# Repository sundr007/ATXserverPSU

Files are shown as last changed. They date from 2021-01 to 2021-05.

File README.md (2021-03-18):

# ATXserverPSU
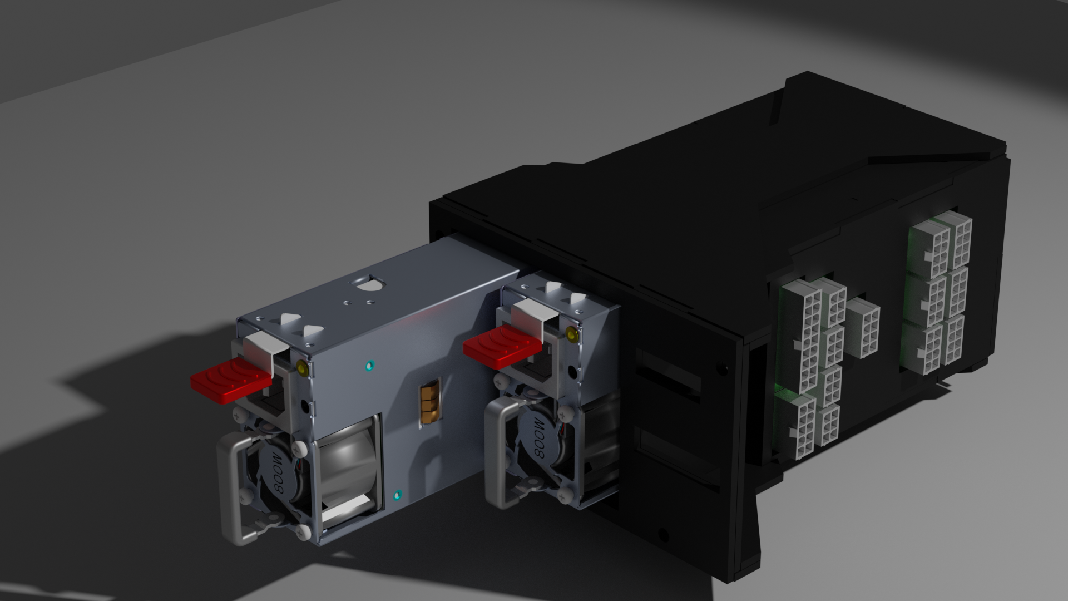
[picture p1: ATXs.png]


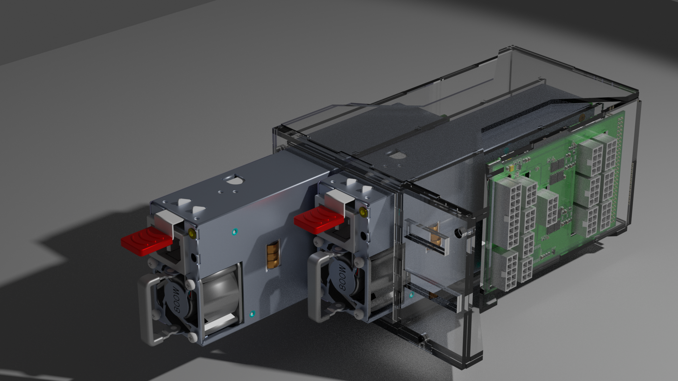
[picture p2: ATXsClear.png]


ATX computer power supply utilizing redundant server power supplies for mining applications.
The Server power supplies will converter AC to 12Vdc with high efficiency.
The ATXs box will then take that 12V, create 5V and 3.3V, supply the needed logic and then provide a modular ATX connector set to connect to the mother board, graphics cards, etc.

The biggest benefit of this system is that the server power supplies will provide very high output power at high efficiency.

The circuit boards are done in KiCAD.
The mechanicals are done in OpenSCAD.

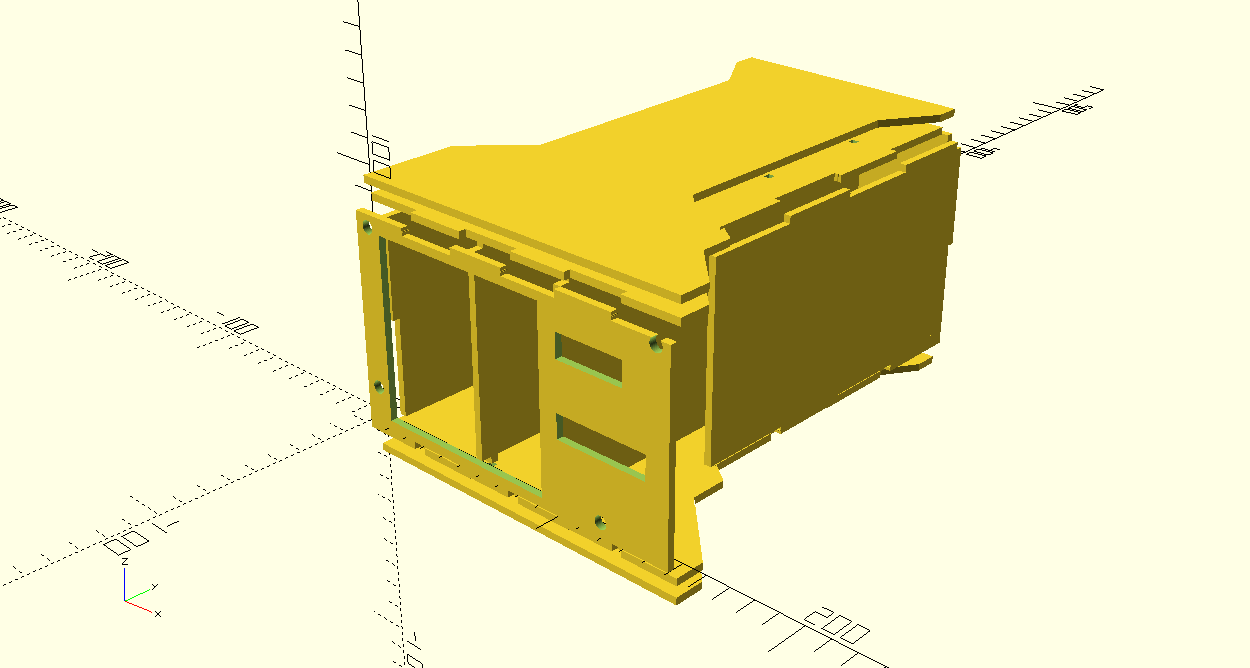
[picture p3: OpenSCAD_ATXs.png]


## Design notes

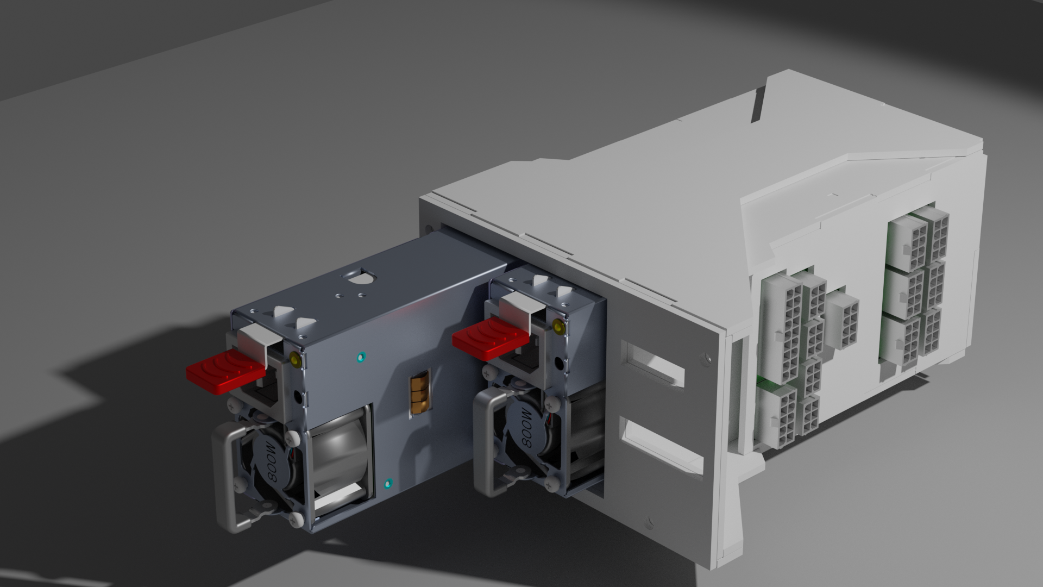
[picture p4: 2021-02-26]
ATXsWhite.png

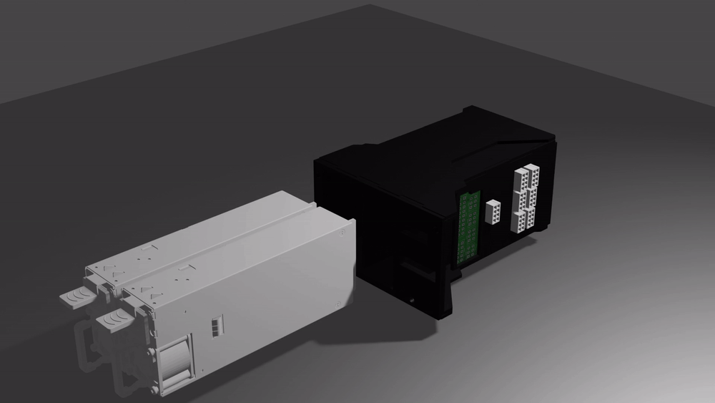
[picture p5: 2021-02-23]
Blender/output.gif

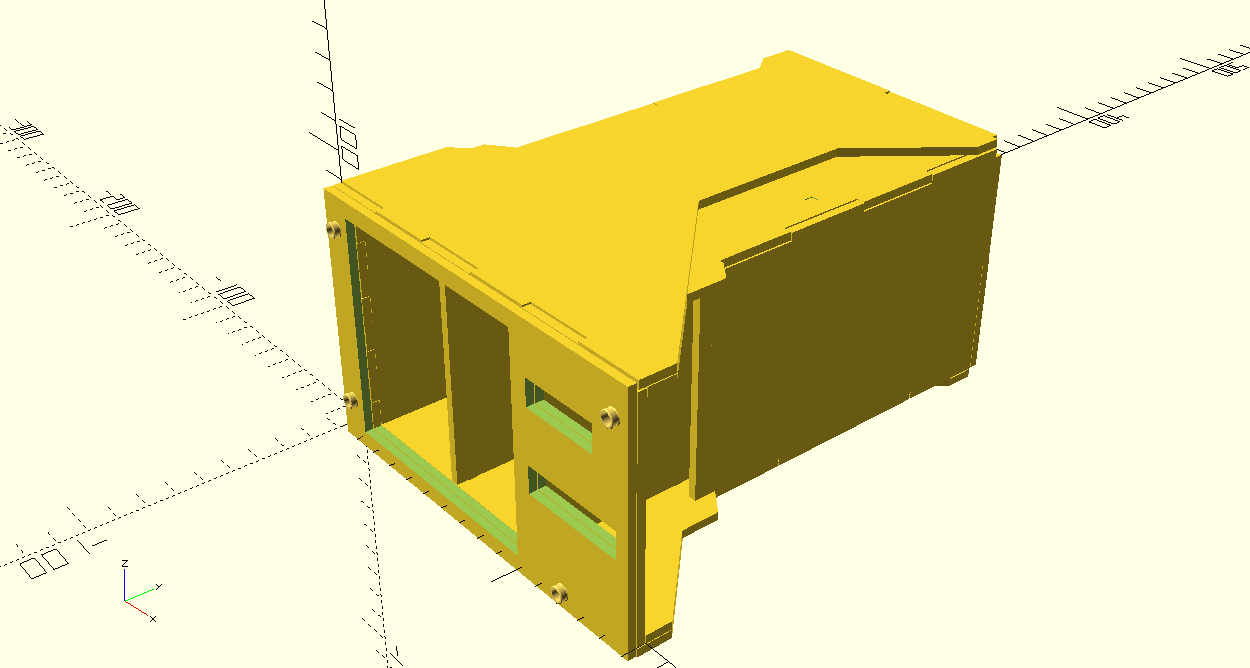
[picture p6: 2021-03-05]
ME-OpenSCAD/ATXs.png

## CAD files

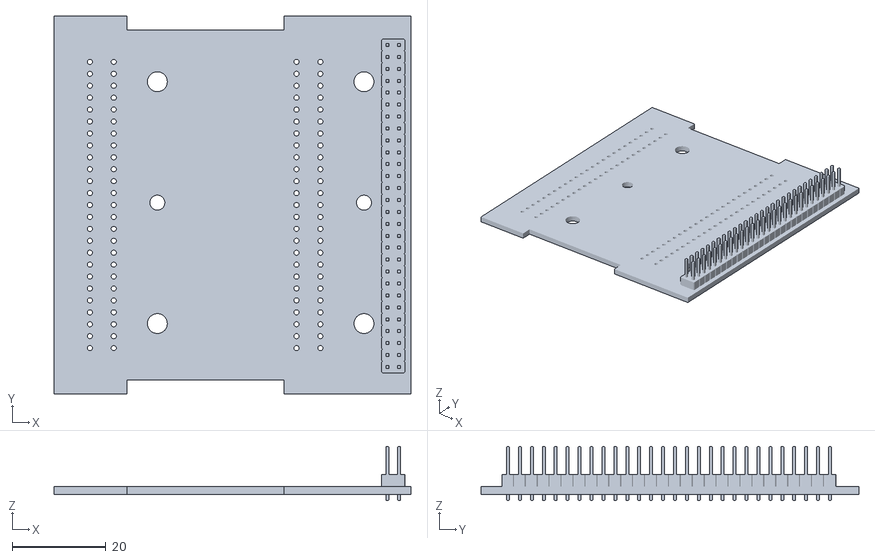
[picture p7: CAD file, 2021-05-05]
ME-OpenSCAD/PCBPSU.stl
76.0 x 80.5 x 11.5

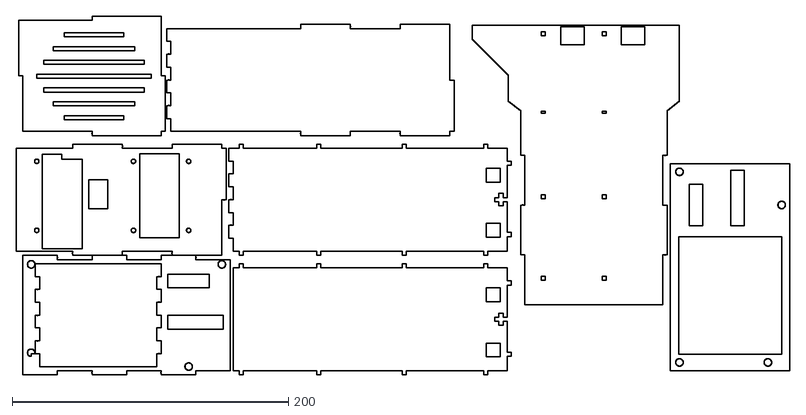
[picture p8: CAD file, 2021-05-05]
ME-OpenSCAD/ATXs1.dxf
560.3 x 259.7

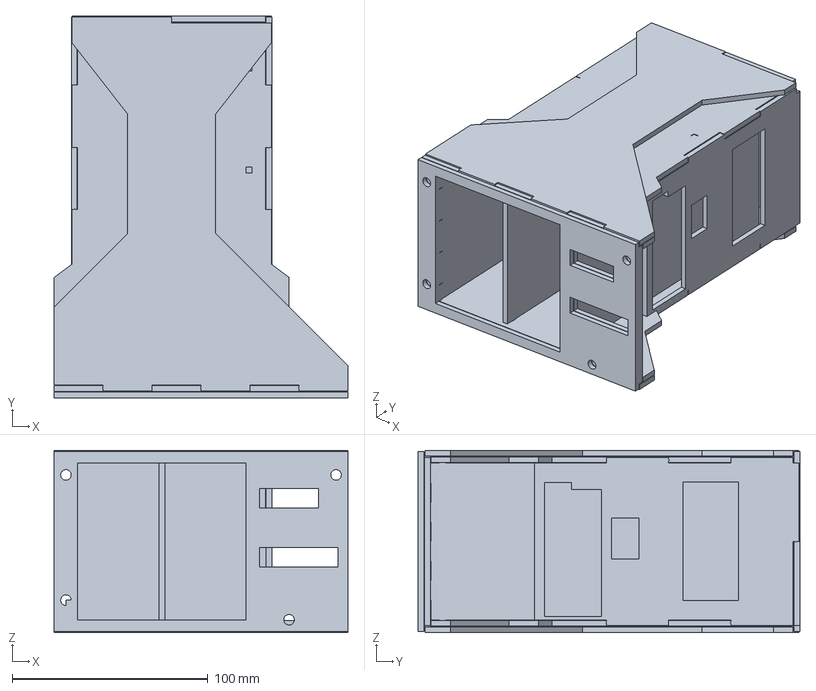
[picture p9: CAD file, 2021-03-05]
ME-OpenSCAD/ATXs.3mf
150.0 x 195.2 x 93.2 mm

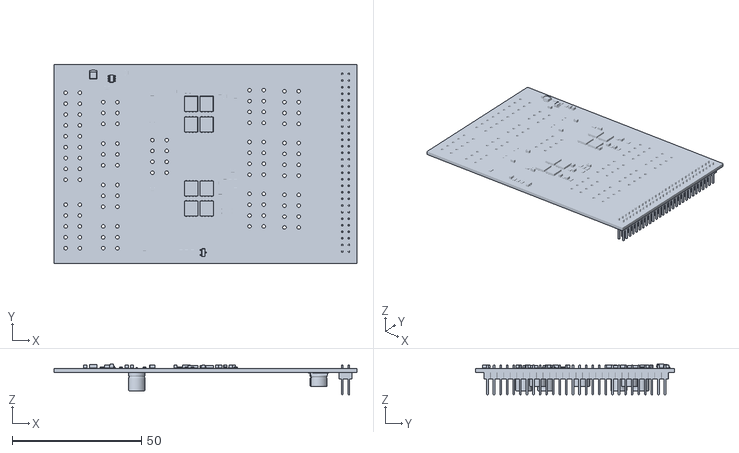
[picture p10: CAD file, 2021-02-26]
ME-OpenSCAD/PCBATX.stl
117.0 x 77.0 x 11.8

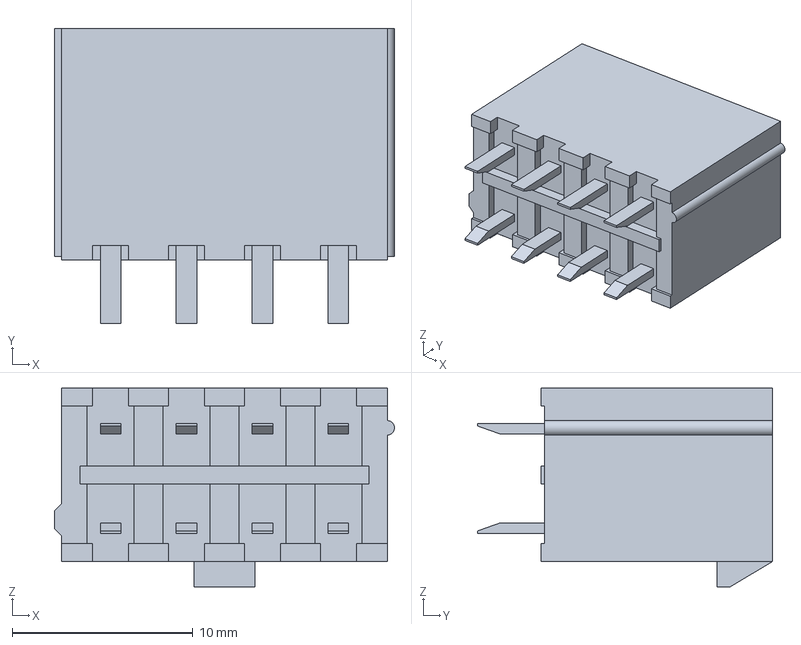
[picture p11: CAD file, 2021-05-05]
Blender/2x8.stp
18.8 x 16.3 x 11.0 mm

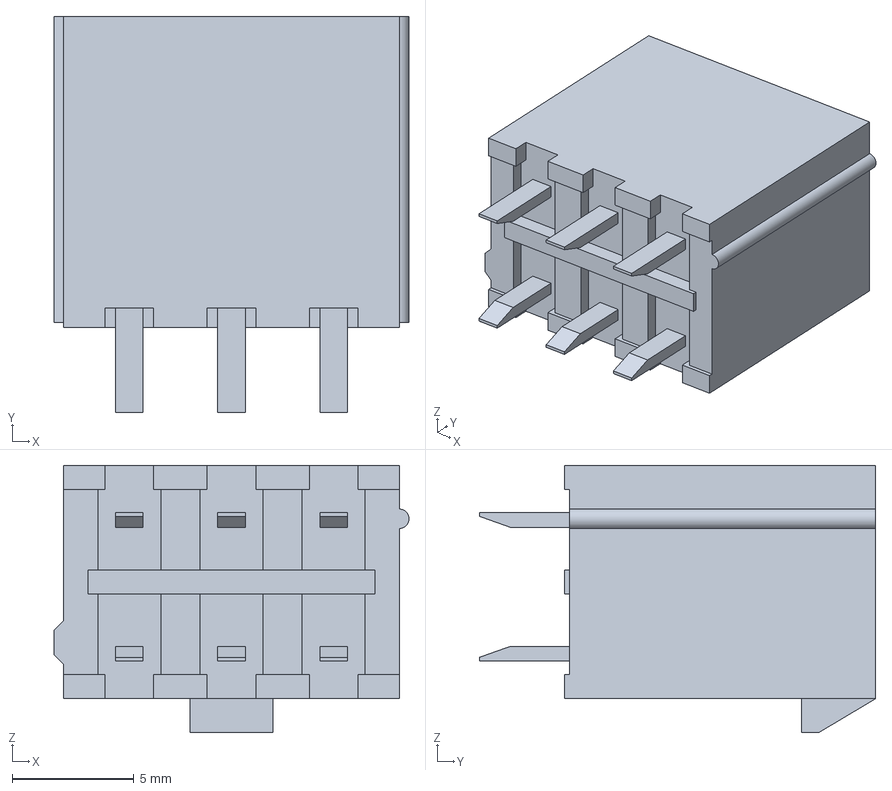
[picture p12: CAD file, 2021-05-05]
Blender/039288060.stp
14.6 x 16.3 x 11.0 mm

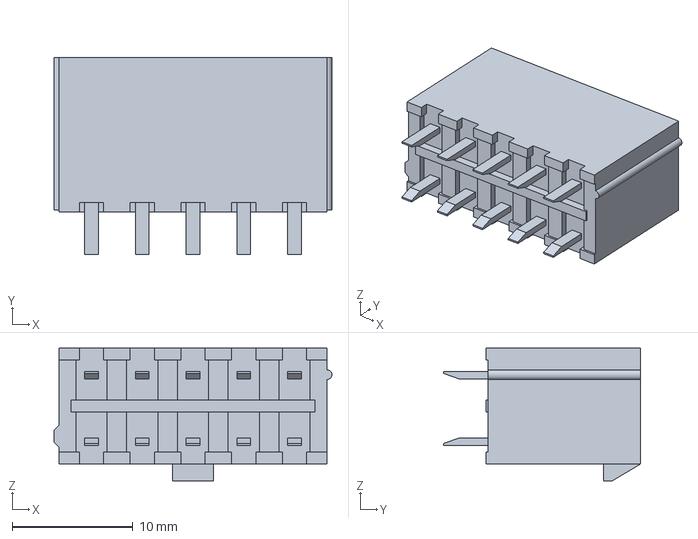
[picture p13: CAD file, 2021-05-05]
Blender/039288100.stp
23.0 x 16.3 x 11.0 mm

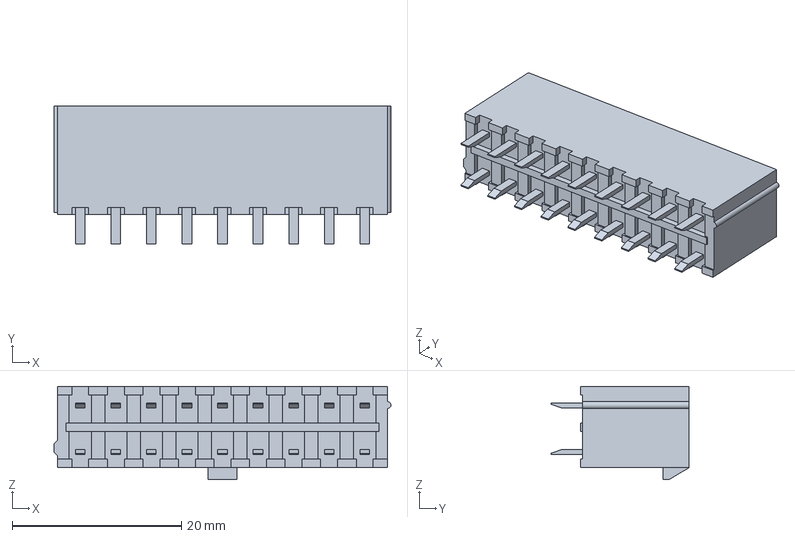
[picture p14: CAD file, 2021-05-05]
Blender/039288180.stp
39.8 x 16.3 x 11.0 mm

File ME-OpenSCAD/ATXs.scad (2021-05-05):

include </home/evan/github/lasercut/lasercut.scad>; 
include <Hex.scad>; 


module ATX_PCB(){
import("PCBATX.stl");
}
module PSU_PCB(){
 import("PCBPSU.stl");
}
module PSU(){
import("PSU.stl");
}

$fn=60;
// ##### RENDERING OPTIONS #####

render_3d   = true;
render_2d   = false;
render_2d2  = false;
render_pcbATX   = false;


// Part Seperation
Sep=10-10*$t;
Sep=0.1;

thickness = 3;

Tape_thickness= 2;
PCB_Thickness = 1.575;
// ATX Front Plate
W = 150;


Hpsu=41;
Lpsu=186;
Wpsu=74.5;
ATXgap=12+3;
PSU_to_psuPCB=18.5;
Backgap=PSU_to_psuPCB- thickness*2+PCB_Thickness+Tape_thickness;

H = Wpsu+thickness*1;

// Top Plate
Wfront = 150;
Wback  = (Hpsu+thickness)*2+ATXgap+thickness;
L      = Lpsu+Backgap;
L1     = 55;
Xindent= 9;
angle =45;
yindent=Xindent*tan(angle);
Yfrontpanelthick=10;

//
Ybacksq = L-(L1+yindent)+6;
Xseperator1 = Xindent+Hpsu+thickness;
Xseperator2 = Xindent+(Hpsu+thickness)*2;
Lseperator  = Lpsu - thickness*2+PSU_to_psuPCB;

// ATX PCB

Watx = Ybacksq -10;
Hatx = H-6; 
PCB_Thick=10;



module pcbATX(){
    //cube([Watx,Hatx,PCB_Thickness]);
ATX_PCB();    
}
module pcbATX3d(){
    translate([Xindent+Wback-thickness+3*Sep-thickness-1.5+0,Lseperator+PCB_Thickness-112.25,thickness])
    rotate([90,0,0])
    rotate([0,90,0])
    color("green",0.5)
    pcbATX();
   

}

module pcbPSU3d(){
    translate([Xseperator2+thickness-75.5+8,Lseperator+PCB_Thickness,thickness])
    rotate([90,0,0])
    color("green",0.5)
    PSU_PCB();
}

module PSU3d(){
       translate([Xindent+Hpsu+2,Lpsu/2-thickness*2,Wpsu/2+thickness])
    rotate([0,0,90])
    color("white",0.5)
    PSU(); 

       translate([Xindent+Hpsu*2+thickness+2,Lpsu/2-thickness*2,Wpsu/2+thickness])
    rotate([0,0,90])
    color("white",0.5)
    PSU(); 
    
    
}

module pcbATX2d(){
    kerf=0.1;
    projection(){
    pcbATX();
        }
}


// ================================================
// Define 3D View
// ================================================

module 3d() {
    FrontMetal3d();
    Front3d();
    Right3d();
    Sep13d();
    Sep23d();
    Top3d();
    Bottom3d();
    Back3d();
    Left3d();
    pcbATX3d();
    pcbPSU3d();
   // PSU3d();
}

// ================================================
// Define 2D View
// ================================================

module 2d() {
    kerf=0.1;
    z=200;
    H=H+thickness*3+.1;
    Wfront=Wfront+thickness*5+.1;
    projection()
    {
            FrontPlateAcrylic();
        translate([0,H, 0]) 
            right();
        translate([0, H*2, 0]) 
            back();
        translate([Wfront-13, 0, 0])  
            Seperator();
        translate([Wfront-13, H, 0])  
            Seperator(1);
        translate([Wfront, H*2, 0])  
            left();
        translate([Wfront*3-20, 250, 0])  
            rotate([0,0,180])
            topPlate();
        translate([Wfront*3+60, 0, 0])  
            rotate([0,0,90])
        FrontPlateMetal();

    }   
}

module 2d2() {
    kerf=0.1;
    z=200;
    H=H+thickness*3+.1;
    Wfront=Wfront+thickness*5+.1;
    projection()
    {



            topPlate();
        translate([Wfront*1, 0, 0])
            topTrim();
        translate([Wfront*2, 0, 0])
            topTrim();
    }}



// ================================================
// Part Positioning
// ================================================
module FrontMetal3d(){
translate([0,-thickness*1-6*Sep,-thickness])
    rotate([90,0,0])
        FrontPlateMetal();
}
module Front3d(){
translate([0,-3*Sep,0])
    rotate([90,0,0])
        FrontPlateAcrylic();
}
module Right3d(){
translate([Xindent+Wback-thickness+3*Sep,L-Ybacksq,thickness])
    rotate([90,0,90])
        right();
}
module Sep13d(){
translate([Xseperator1,0,thickness])
    rotate([90,0,90])
        Seperator();
}
module Sep23d(){
translate([Xseperator2,0,thickness])
    rotate([90,0,90])
        Seperator(1);
}
module Top3d(){
translate([0,0,H+Sep*3]){
    top();
}
}
module Bottom3d(){
translate([0,0,-Sep*3]){
    bottom();
}
}
module Back3d(){
rotate([90,0,0])
    translate([Xindent+thickness,0,-L-thickness-Sep*6])
        back();
    }
module Left3d(){
translate([Xindent-Sep*3,L-Ybacksq,thickness])
    rotate([90,0,90])
    left();
}


// ================================================
// Part Definitions
// ================================================

module topPlate()
{
    Wback = Wback - 2*thickness;
    Xindent = Xindent + thickness;
    L = L - thickness;
    
    points = [[0,0], [0,L1], [Xindent,L1+Xindent], [Xindent,L+yindent-thickness*2], [Xindent+Wback,L+yindent-thickness*2], [Xindent+Wback,L1+Xindent], [2*Xindent+Wback,L1], [2*Xindent+Wback,Yfrontpanelthick+(Wfront-(2*Xindent+Wback))], [Wfront,Yfrontpanelthick], [Wfront,0]];
    
    difference(){
        union(){
    lasercutout(thickness=thickness, points = points,
    simple_tab_holes=[
                [MID,Xseperator1, 0+thickness*1.5],
                [MID,Xseperator1, (Lpsu)*1/3-thickness/2],
                [MID,Xseperator1, (Lpsu)*2/3-thickness/2],
                [MID,Xseperator1, Lpsu-thickness*1.5],
    
                [MID,Xseperator2, 0+thickness*1.5],
                [MID,Xseperator2, (Lpsu)*1/3-thickness/2],
                [MID,Xseperator2, (Lpsu)*2/3-thickness/2],
                [MID,Xseperator2, Lpsu-thickness*1.5],
            ],
                    cutouts = [
            [Xindent+Hpsu/2-7.5, 1, 17, 13],
            [Xindent+Hpsu+thickness+Hpsu/2-7.5, 1, 17, 13],
            [Wback+7.8,87.5,1.7,27],
            [Wback+7.8,155.6,1.7,22.5],
            [Wback-19,L-0.65,28,1.7],
            [32,L-0.65,17,1.7],
            ]
    

    );
    translate([Xindent,L1+yindent-thickness*2,0])
        lasercutoutSquare(thickness=thickness, x=Wback, y=Ybacksq,
            bumpy_finger_joints=[
               // [UP, 1, 1],
                [LEFT, 1, 2],
                [RIGHT, 2, 2]
            ],
            cutouts = [
            [Xindent, 4, 87,Lpsu-(L1-thickness*3)]
    ]
    );
}}}

module topTrim()
{
    Wgap=45;
    L=L;
    Y1 = Yfrontpanelthick+(Wfront-(2*Xindent+Wback));
    Xinner1 = Xindent+(Wback-Wgap)/2;
    Xinner2 = Xinner1+Wgap;
    
    points = [[0,0], [0,Y1], [Xinner1,Y1+Xinner1], [Xinner1,L-Xinner1-Xindent], [Xindent,L-Yfrontpanelthick], [Xindent,L], [Xindent+Wback,L], [Xindent+Wback,L-Yfrontpanelthick], [Xinner2,L-Xinner1-Xindent], [Xinner2,Y1+Xinner1], [Wfront,Yfrontpanelthick], [Wfront,0]];
    lasercutout(thickness=thickness, points = points);  
    
    translate([Xindent,L-thickness,0])
        lasercutoutSquare(thickness=thickness, x=Wback, y=thickness,
            bumpy_finger_joints=[
                [UP, 1, 1]
            ]
    );
    
    translate([0,0,0])
        lasercutoutSquare(thickness=thickness, x=Wfront,        y=thickness/2,
            bumpy_finger_joints=[
                [DOWN, 1, 3]
            ]
    );
}

module top(){
    topPlate();
    translate([0,0,3+Sep*3])
        topTrim();
}

module bottom(){
    topPlate();
    translate([0,0,-3-Sep*3])
        topTrim();
}

module back()
{
    H=H-thickness;
    difference(){
    width = (Wback-2*thickness);
        
    lasercutoutSquare(thickness=thickness, x=Wback-2*thickness, y=H+thickness*2,
    bumpy_finger_joints=[
            [UP, 0, 1],
            [DOWN, 1, 1],
            [LEFT, 0, 1],
            [RIGHT, 0, 1]
        ],
        slits = [
        [RIGHT,width*0.7,10,width*(1-(1-0.70)*2)],
        [RIGHT,width*0.78,20,width*(1-(1-0.78)*2)],
        [RIGHT,width*0.85,30,width*(1-(1-0.85)*2)],
        [RIGHT,width*0.9,40,width*(1-(1-0.9)*2)],
        [RIGHT,width*0.85,50,width*(1-(1-0.85)*2)],
        [RIGHT,width*0.78,60,width*(1-(1-0.78)*2)],
        [RIGHT,width*0.70,70,width*(1-(1-0.7)*2)]
        ]
    );  
        
    radius = 3;
    latticeWidth = 13;
    latticeLength = 11;
    spacing = 2.1;
    height = 4;
//    translate([3,6,-0.5])
//    difference(){
//        cube([(latticeLength-1)*(spacing+radius*2)
//        ,(latticeWidth)*(spacing+radius),4]);
//    honeycomb(radius,latticeWidth,latticeLength,spacing,height);
//    }
        

    }
}
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

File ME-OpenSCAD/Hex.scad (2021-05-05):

//radius = 12;
//latticeWidth = 4;
//latticeLength = 3;
//spacing = 10;
//height = 1;

module honeycomb(radius,latticeWidth,latticeLength,spacing,height){
difference() {  

        linear_extrude(height) {
        for(j = [0:latticeWidth-1]) {
            translate([(((sqrt(3)*radius)+spacing)/2)*(j%2),sqrt(pow((((((sqrt(3)))*radius)+spacing)),2)-(pow(((((sqrt(3)*radius)+spacing))/2),2)))*j,0]) {
                for(i = [0:latticeLength-1]) {
                    translate([((sqrt(3)*radius*i)+spacing*i),0,0]) {
                        rotate([0,0,30]) {
                            circle(((sqrt(3)*radius)+(spacing*2))/sqrt(3), $fn = 6);
                        }
                    }
                }
            }
        }
    }
        linear_extrude(height) {
        for(j = [0:latticeWidth-1]) {
            translate([((sqrt(3)*radius)+spacing)/2*(j%2),sqrt((pow(((sqrt(3)*radius)+spacing),2))-(pow((((sqrt(3)*radius)+spacing))/2,2)))*j,0]) {
                for(i = [0:latticeLength-1]) {
                    translate([(sqrt(3)*radius*i)+spacing*i,0,0]) {
                        rotate([0,0,30]) {
                            circle(radius, $fn = 6);
                        }
                    }
                }
            }
        }
    } 


}
}

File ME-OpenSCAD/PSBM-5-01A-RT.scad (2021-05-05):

$fn=60;

cube([13,13,2+0.8],true);
translate([0,0,7.9/2])
cylinder(7.9,4.37/2,4.37/2,true);

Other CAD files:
Blender/psu.obj
Blender/2x8.stl
ME-OpenSCAD/ATXs.amf
ME-OpenSCAD/ATXs.stl
ME-OpenSCAD/pcbATX.dxf

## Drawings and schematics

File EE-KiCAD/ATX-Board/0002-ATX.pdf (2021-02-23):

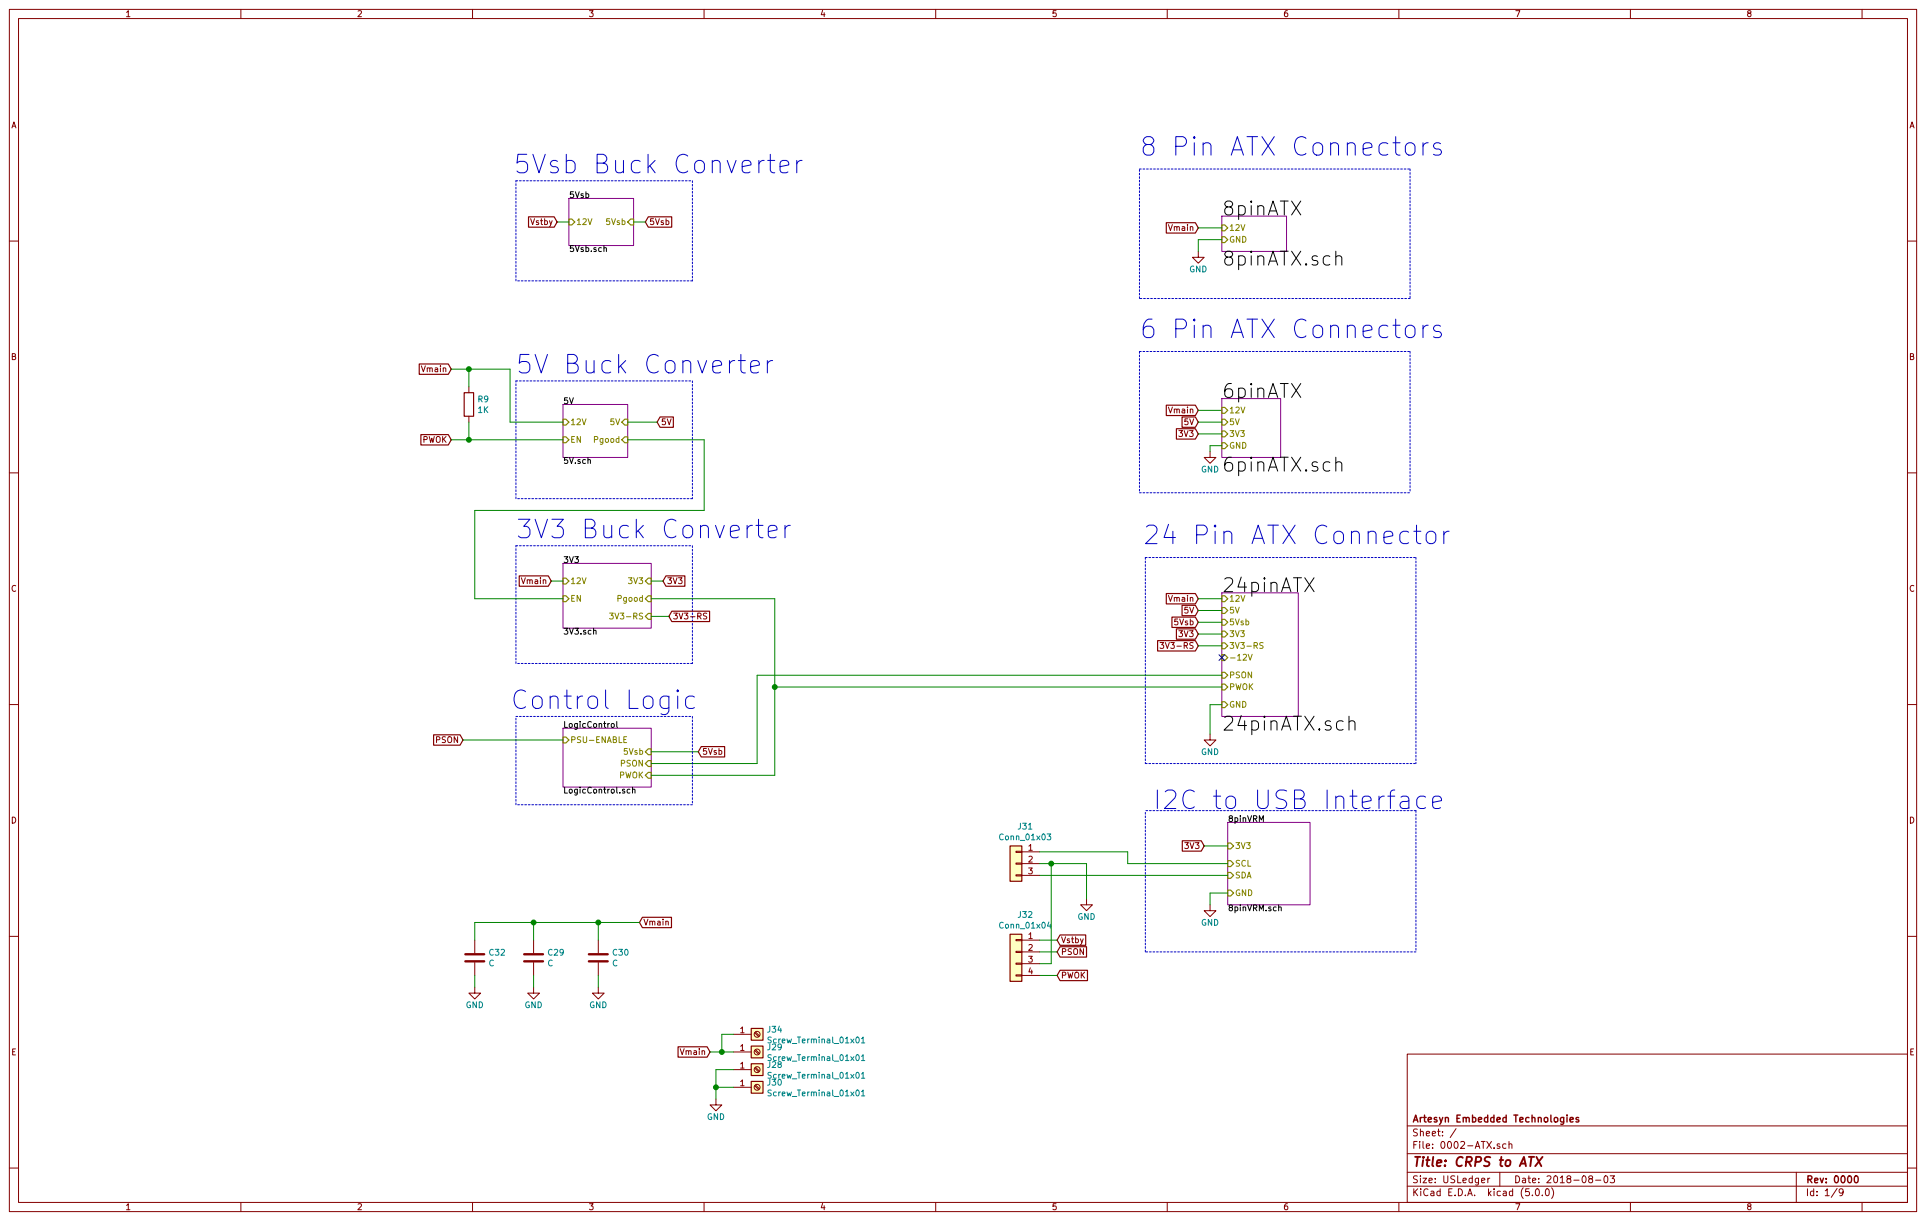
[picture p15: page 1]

Vmain 8 Pin ATX Connectors

Vmain 6 Pin ATX Connectors

Vmain 24 Pin ATX Connector

LogicControl
LogicControl.sch PSU-ENABLE

Id: 1/9 Title: CRPS to ATX

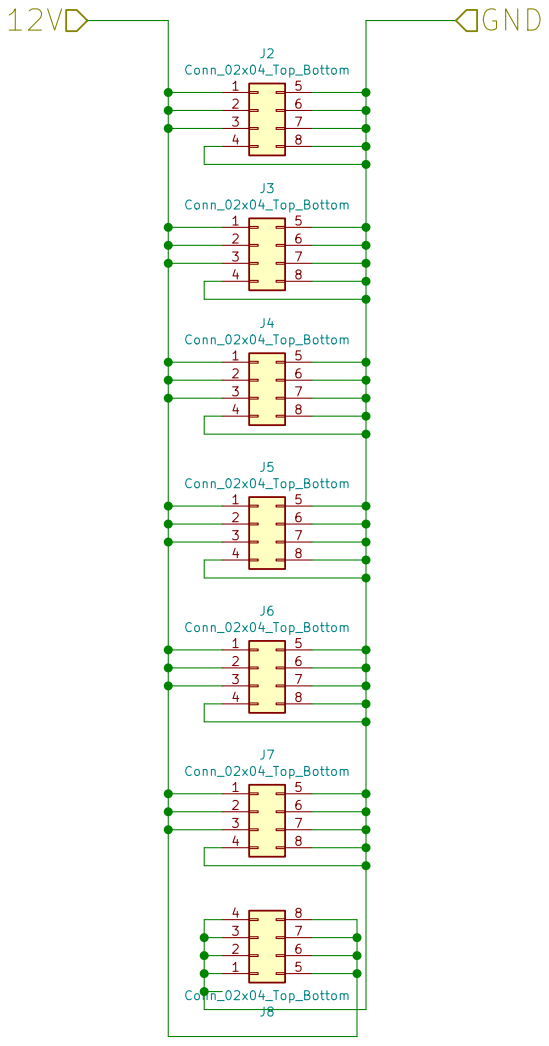
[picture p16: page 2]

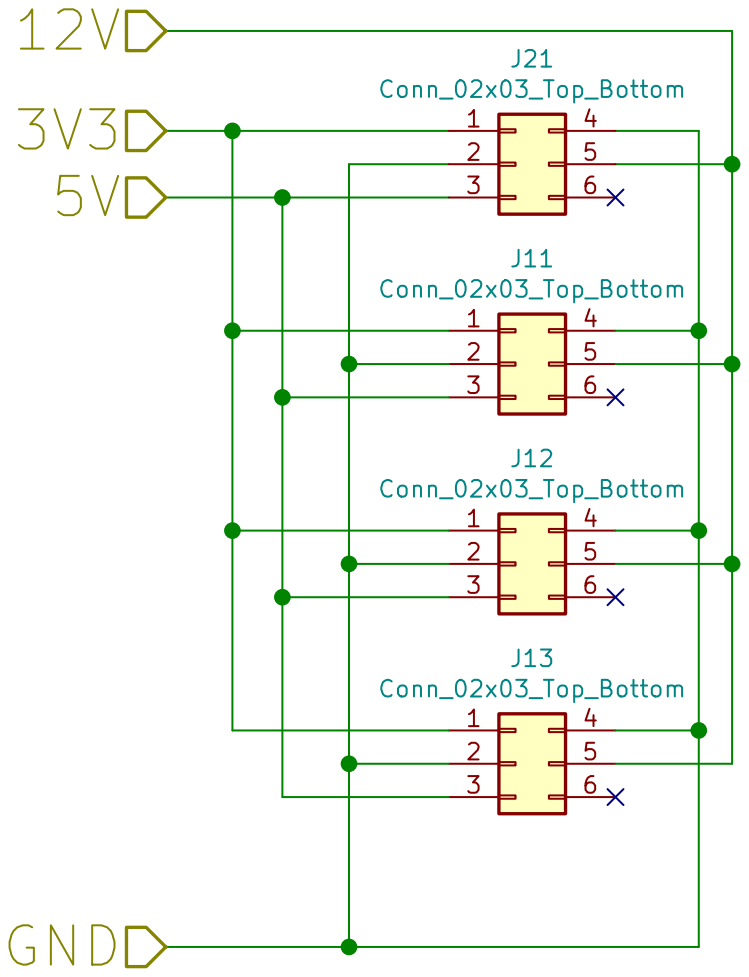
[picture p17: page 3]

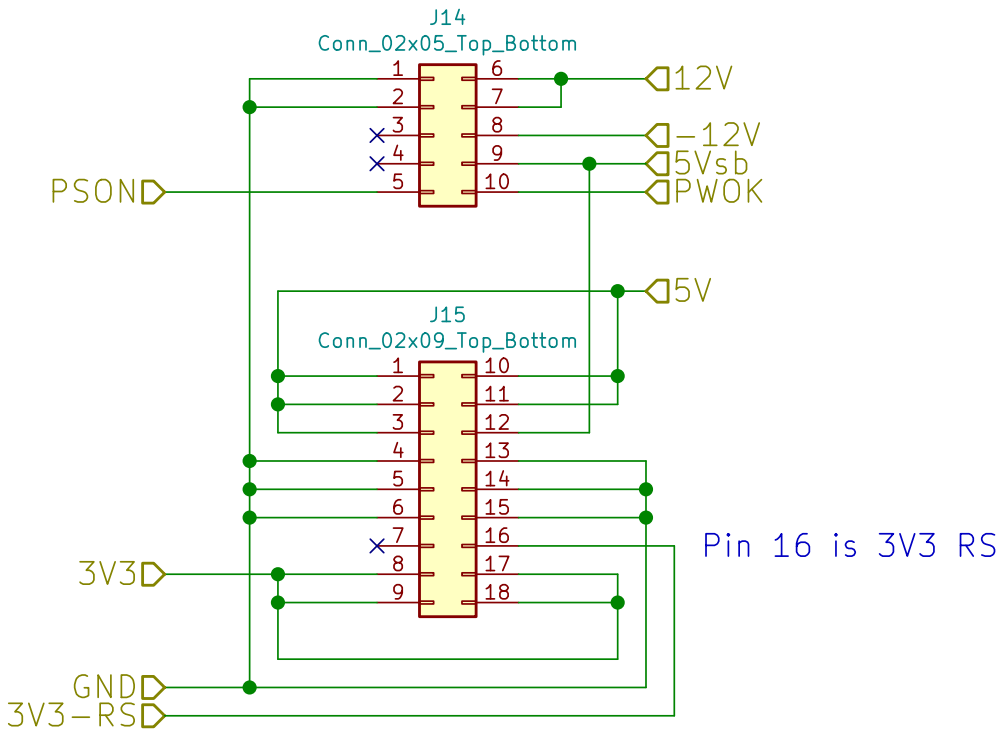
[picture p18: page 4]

J15 Conn_02x09_Top_Bottom

2 | 11
3 | 12

5 | 14
6 | 15
7 8 | 16

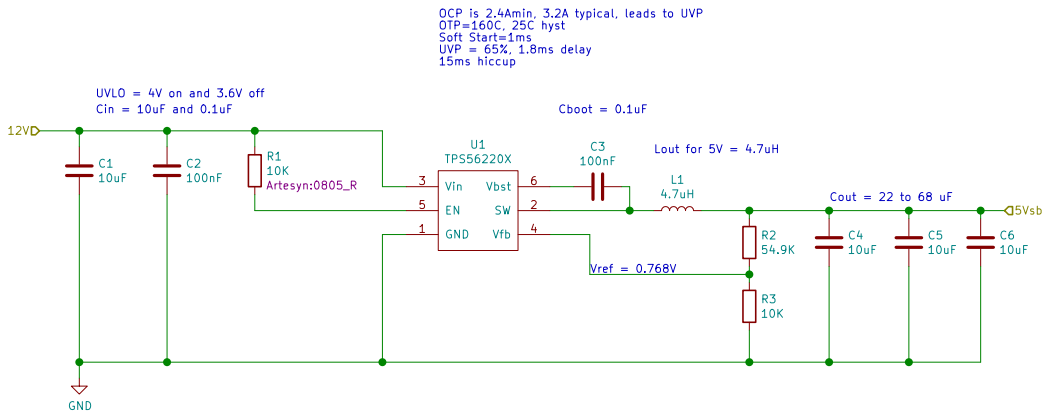
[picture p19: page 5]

Cout = 22 to 68 uF OCP is 2.4Amin, 3.2A typical, leads to UVP
OTP=160C, 25C hyst Soft Start=1ms UVP = 65%, 1.8ms delay

Id: 5/9 Title: File: 5Vsb.sch Sheet: /5Vsb/

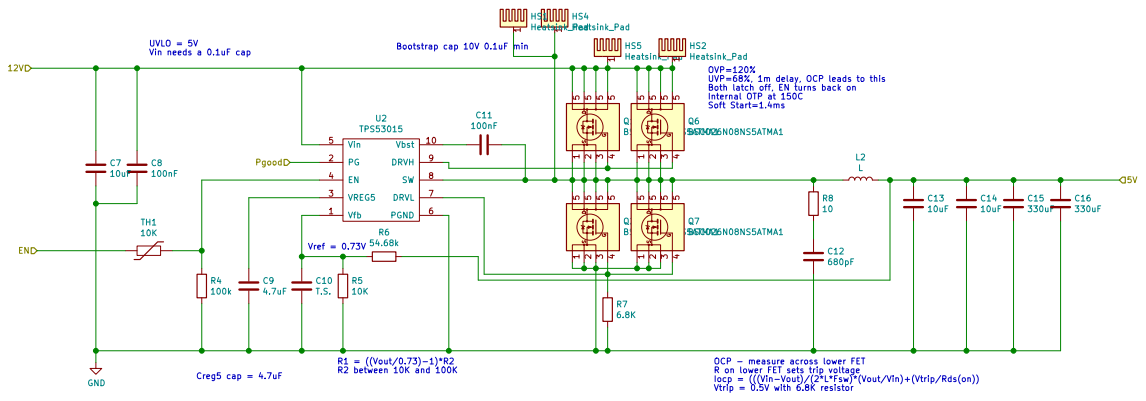
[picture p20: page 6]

UVP=68%, 1m delay, OCP leads to this Both latch off, EN turns back on
Internal OTP at 150C

Iocp = (((Vin-Vout)/(2*L*Fsw)*(Vout/Vin)+(Vtrip/Rds(on))
Vtrip = 0.5V with 6.8K resistor

Id: 6/9 Title: File: 5V.sch Sheet: /5V/

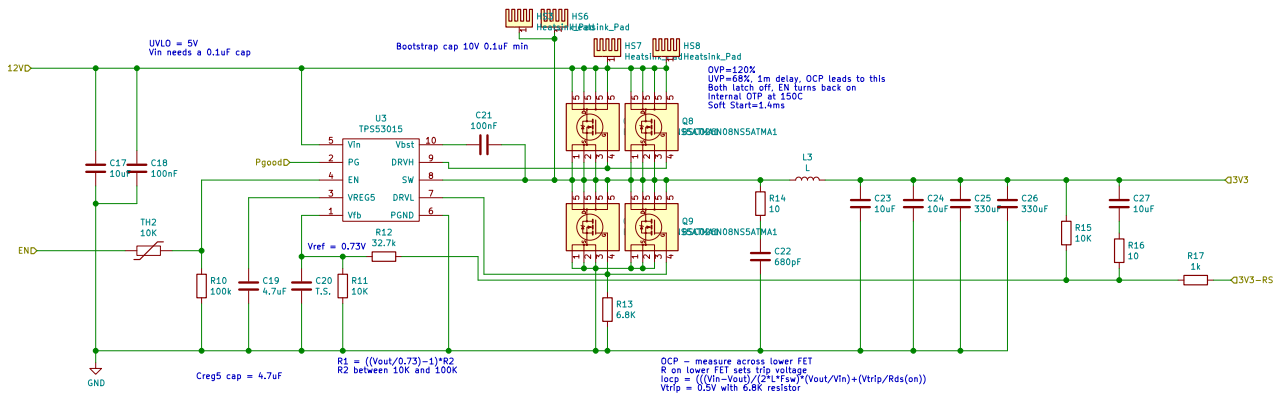
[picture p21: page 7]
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

Id: 7/9 Title: File: 3V3.sch Sheet: /3V3/

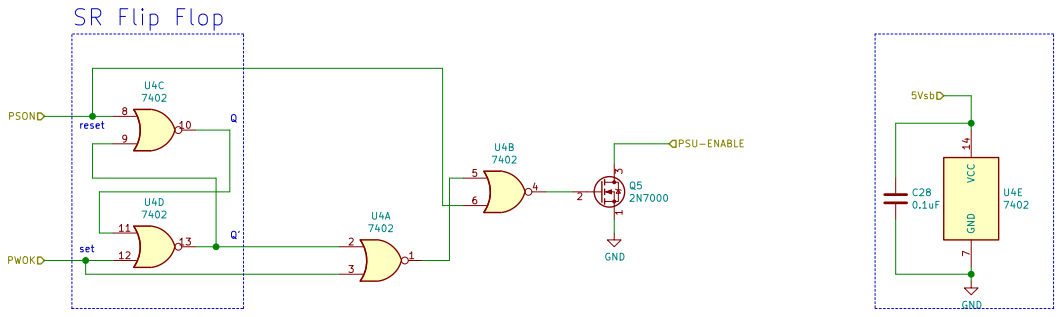
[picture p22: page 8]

7402 GND SR Flip Flop

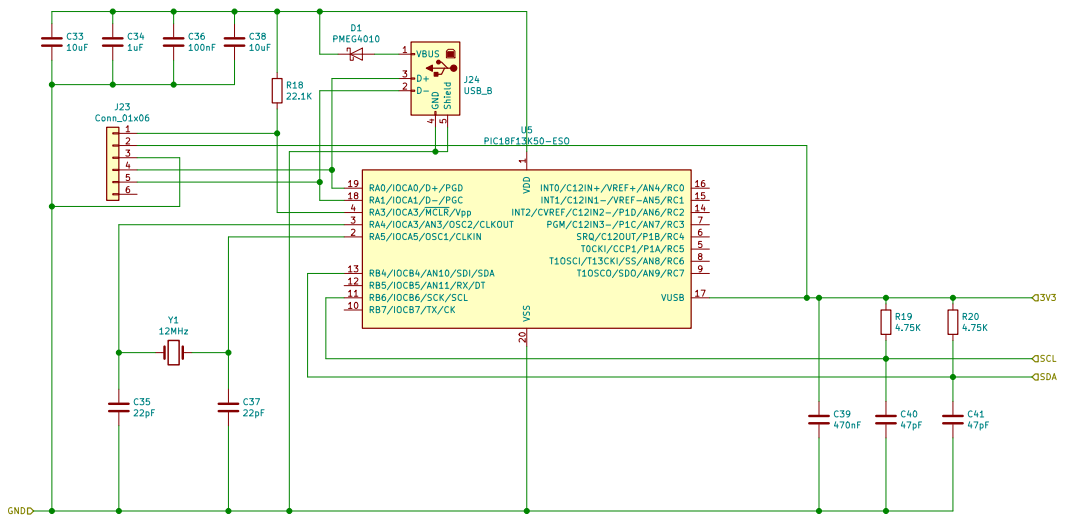
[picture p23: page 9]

1 RB7/IOCB7/TX/CK 10 RB6/IOCB6/SCK/SCL 11 RB5/IOCB5/AN11/RX/DT 12 RB4/IOCB4/AN10/SDI/SDA 13

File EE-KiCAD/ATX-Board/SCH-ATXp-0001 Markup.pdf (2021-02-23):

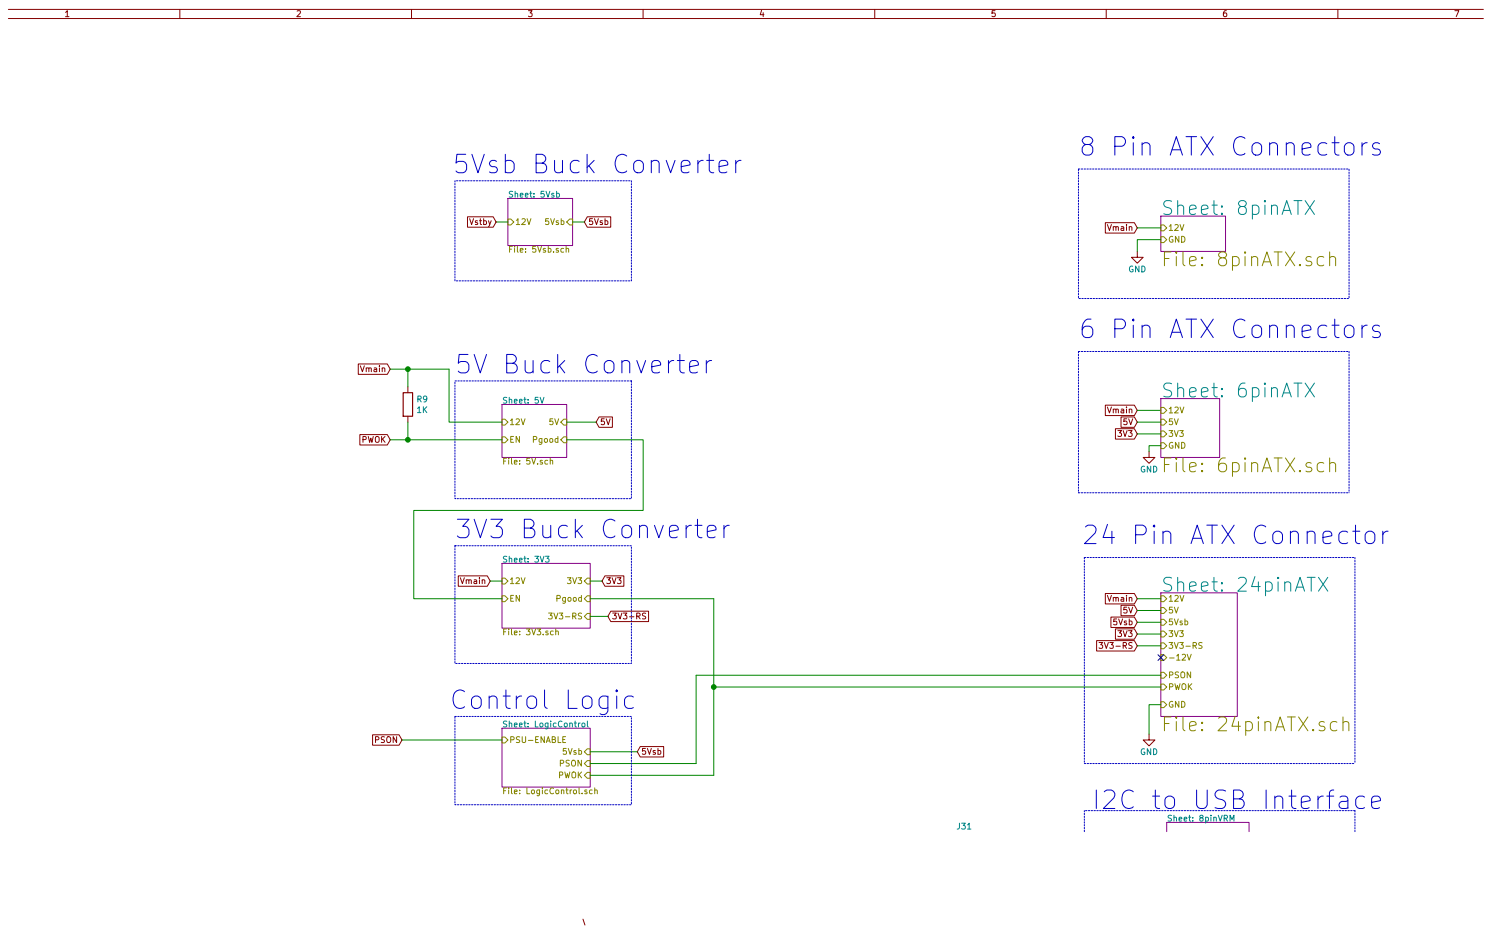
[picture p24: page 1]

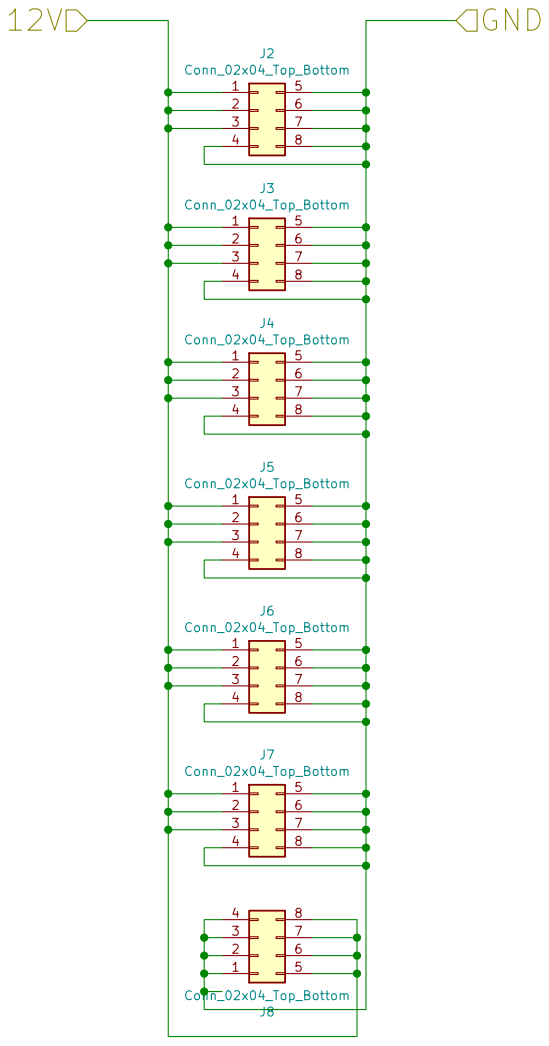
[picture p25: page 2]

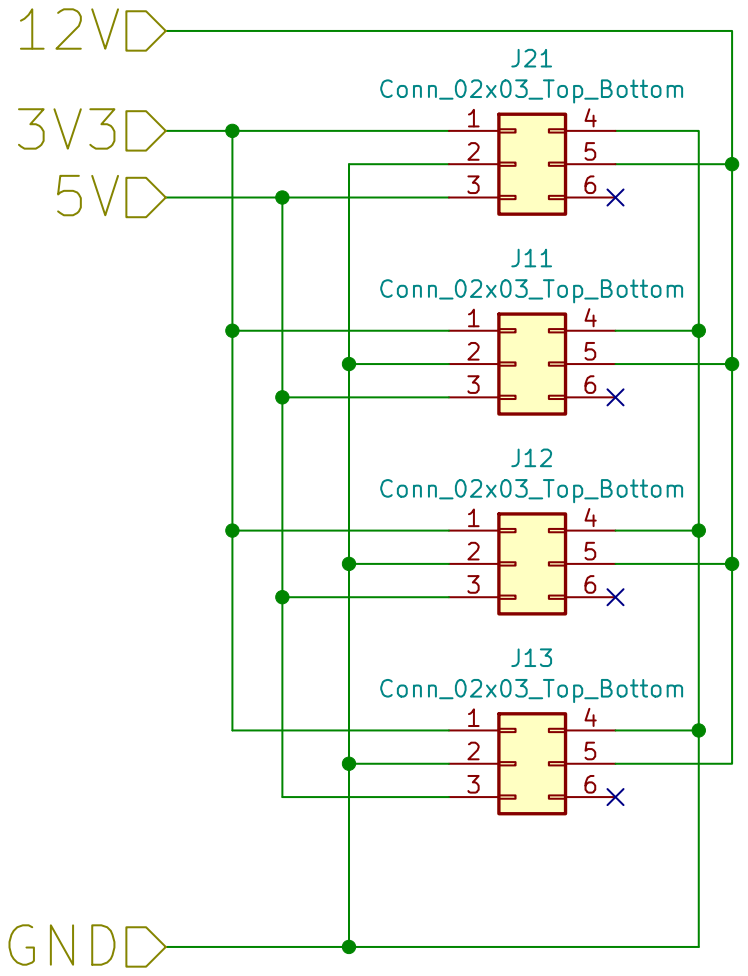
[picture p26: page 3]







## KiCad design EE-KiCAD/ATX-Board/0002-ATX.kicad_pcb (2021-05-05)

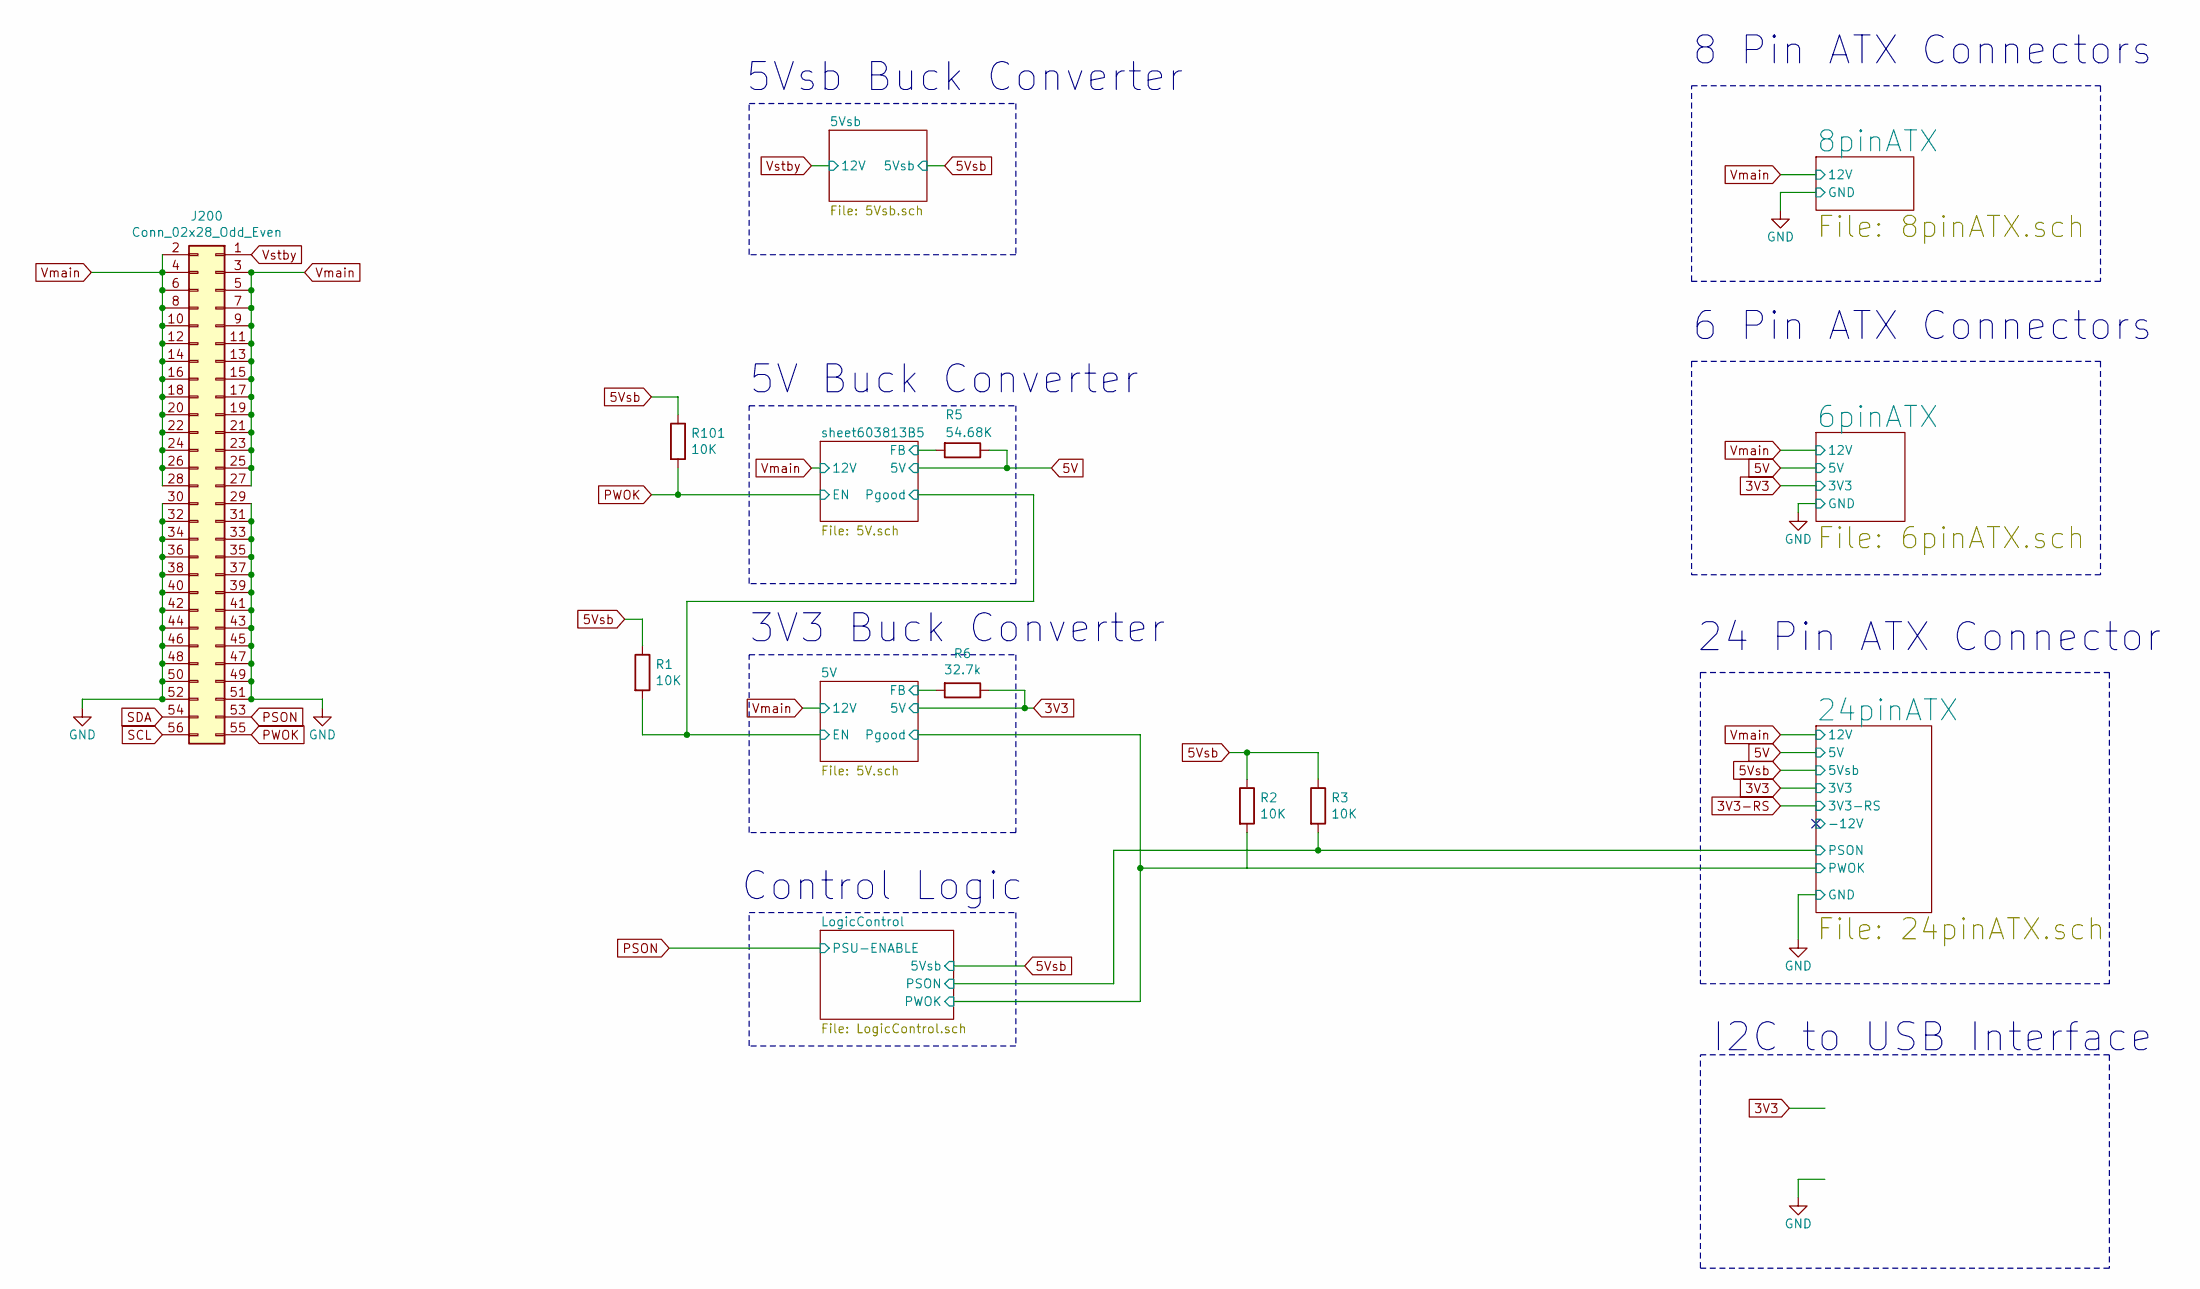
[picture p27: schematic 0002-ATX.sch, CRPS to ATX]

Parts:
J200: Conn_02x28_Odd_Even; PinSocket_2x28_P2.54mm_Horizontal
R1, R2, R3, R101: 10K; 0805_R
R5: 54.68K; 0805_R
R6: 32.7k; 0805_R

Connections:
3V3: R6.1; also elsewhere on the board
5V: R5.1; also elsewhere on the board
5Vsb: R1.1, R2.1, R3.1, R101.1; also elsewhere on the board
/5V/EN: R1.2; also elsewhere on the board
/5V/FB: R6.2; also elsewhere on the board
/24pinATX/PSON: R3.2; also elsewhere on the board
/sheet603813B5/FB: R5.2; also elsewhere on the board
GND: J200.29, J200.30, J200.31, J200.32, J200.33, J200.34, J200.35, J200.36, J200.37, J200.38, J200.39, J200.40, J200.41, J200.42, J200.43, J200.44, J200.45, J200.46, J200.47, J200.48, J200.49, J200.50, J200.51, J200.52; also elsewhere on the board
PSON: J200.53; also elsewhere on the board
PWOK: J200.55, R101.2; also elsewhere on the board
SCL: J200.56
SDA: J200.54
Vmain: J200.2, J200.3, J200.4, J200.5, J200.6, J200.7, J200.8, J200.9, J200.10, J200.11, J200.12, J200.13, J200.14, J200.15, J200.16, J200.17, J200.18, J200.19, J200.20, J200.21, J200.22, J200.23, J200.24, J200.25, J200.26, J200.27, J200.28; also elsewhere on the board
Vstby: J200.1; also elsewhere on the board

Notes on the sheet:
8 Pin ATX Connectors
6 Pin ATX Connectors
24 Pin ATX Connector
5Vsb Buck Converter
5V Buck Converter
3V3 Buck Converter
Control Logic
I2C to USB Interface

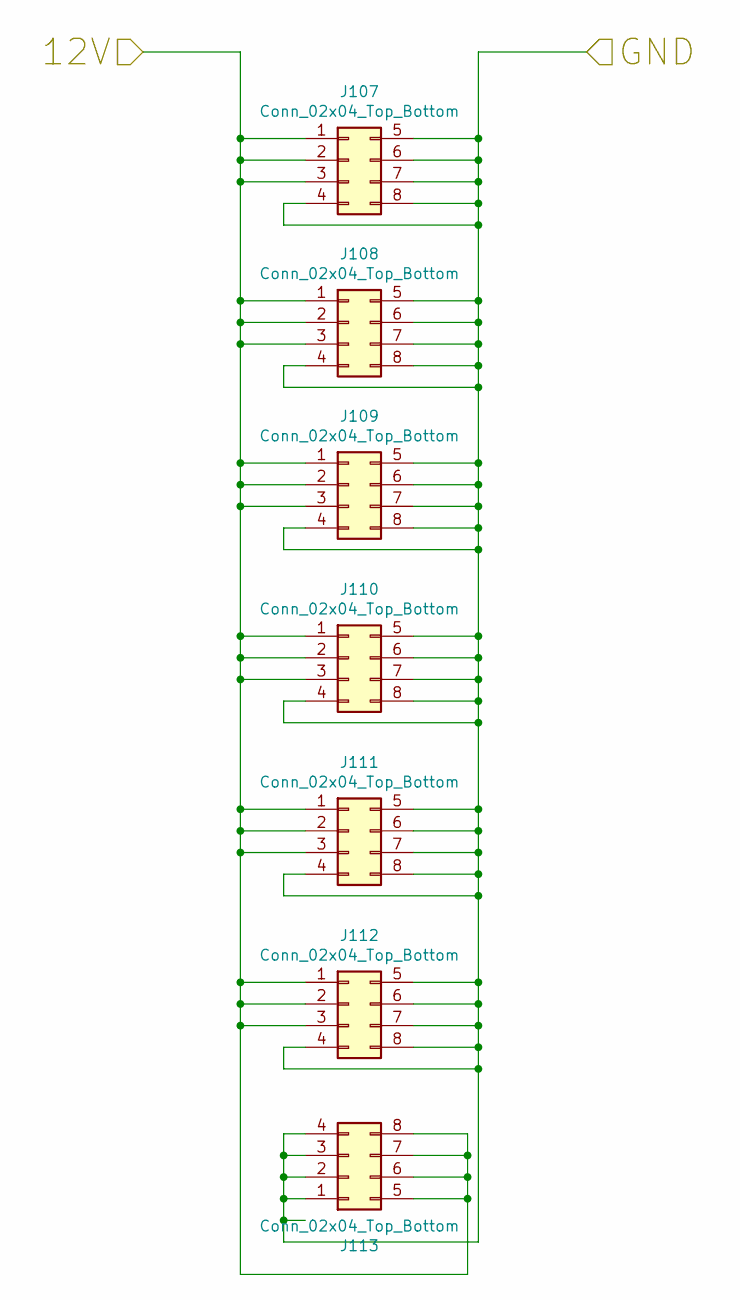
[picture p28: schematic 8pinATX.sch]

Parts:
J107, J108, J109, J110, J111, J112, J113: Conn_02x04_Top_Bottom; Molex_Mini-Fit_Jr_5566-08A_2x04_P4.20mm_Vertical

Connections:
GND: J107.4, J107.5, J107.6, J107.7, J107.8, J108.4, J108.5, J108.6, J108.7, J108.8, J109.4, J109.5, J109.6, J109.7, J109.8, J110.4, J110.5, J110.6, J110.7, J110.8, J111.4, J111.5, J111.6, J111.7, J111.8, J112.4, J112.5, J112.6, J112.7, J112.8, J113.1, J113.2, J113.3, J113.4; also elsewhere on the board
Vmain: J107.1, J107.2, J107.3, J108.1, J108.2, J108.3, J109.1, J109.2, J109.3, J110.1, J110.2, J110.3, J111.1, J111.2, J111.3, J112.1, J112.2, J112.3, J113.5, J113.6, J113.7, J113.8; also elsewhere on the board

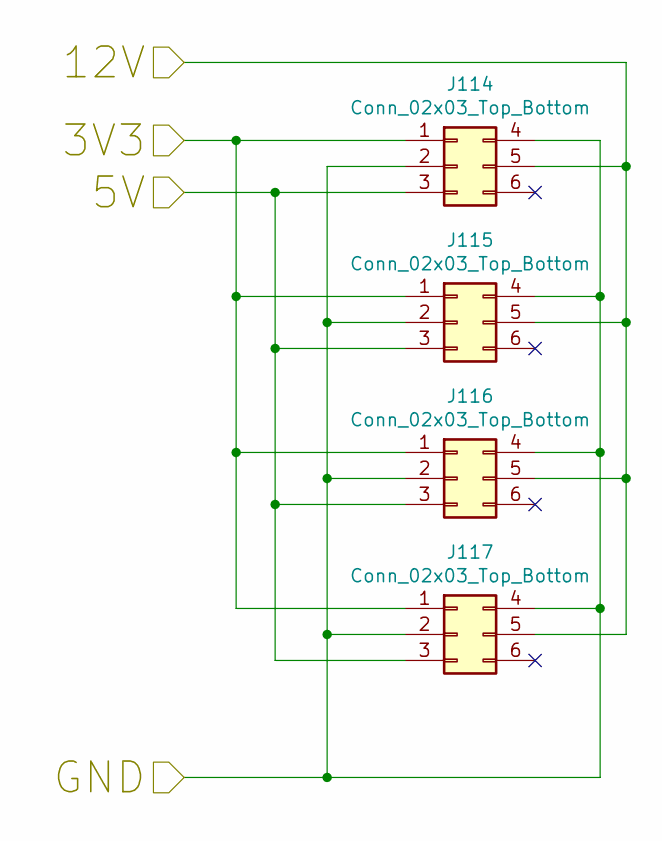
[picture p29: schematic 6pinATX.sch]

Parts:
J114, J115, J116, J117: Conn_02x03_Top_Bottom; Molex_Mini-Fit_Jr_5566-06A_2x03_P4.20mm_Vertical

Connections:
3V3: J114.1, J115.1, J116.1, J117.1; also elsewhere on the board
5V: J114.3, J115.3, J116.3, J117.3; also elsewhere on the board
GND: J114.2, J114.4, J115.2, J115.4, J116.2, J116.4, J117.2, J117.4; also elsewhere on the board
Vmain: J114.5, J115.5, J116.5, J117.5; also elsewhere on the board

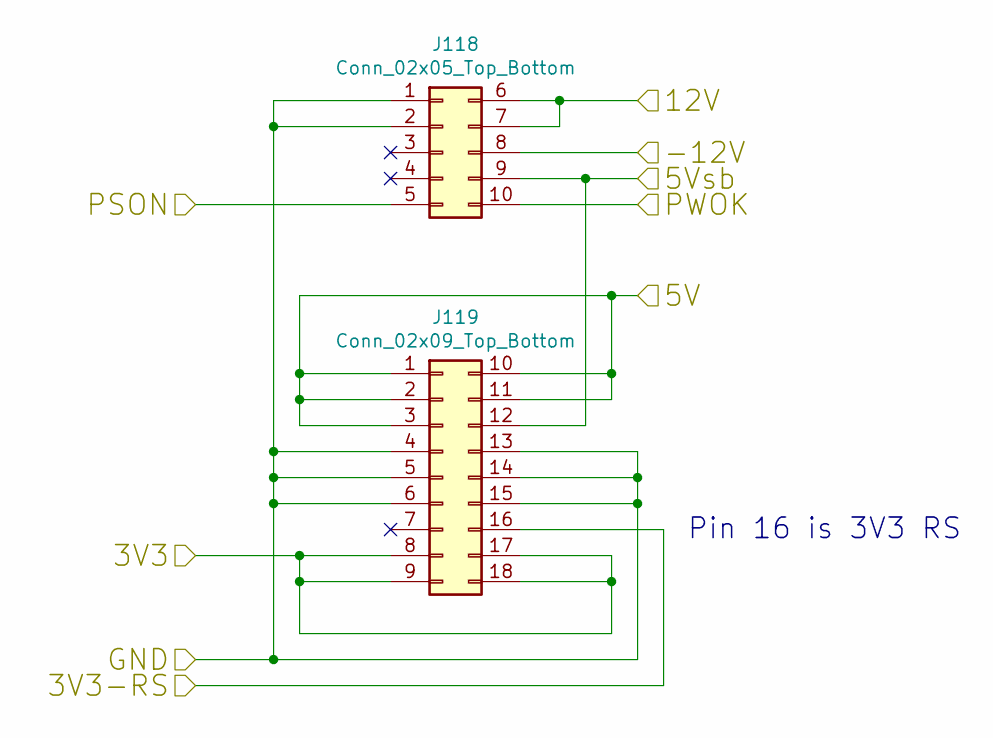
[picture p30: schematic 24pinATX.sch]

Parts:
J118: Conn_02x05_Top_Bottom; Molex_Mini-Fit_Jr_5566-10A_2x05_P4.20mm_Vertical
J119: Conn_02x09_Top_Bottom; Molex_Mini-Fit_Jr_5566-18A_2x09_P4.20mm_Vertical

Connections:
3V3: J119.8, J119.9, J119.17, J119.18; also elsewhere on the board
3V3-RS: J119.16
5V: J119.1, J119.2, J119.3, J119.10, J119.11; also elsewhere on the board
5Vsb: J118.9, J119.12; also elsewhere on the board
/24pinATX/-12V: J118.8
/24pinATX/PSON: J118.5; also elsewhere on the board
/24pinATX/PWOK: J118.10; also elsewhere on the board
GND: J118.1, J118.2, J119.4, J119.5, J119.6, J119.13, J119.14, J119.15; also elsewhere on the board
Vmain: J118.6, J118.7; also elsewhere on the board

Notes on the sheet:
Pin 16 is 3V3 RS

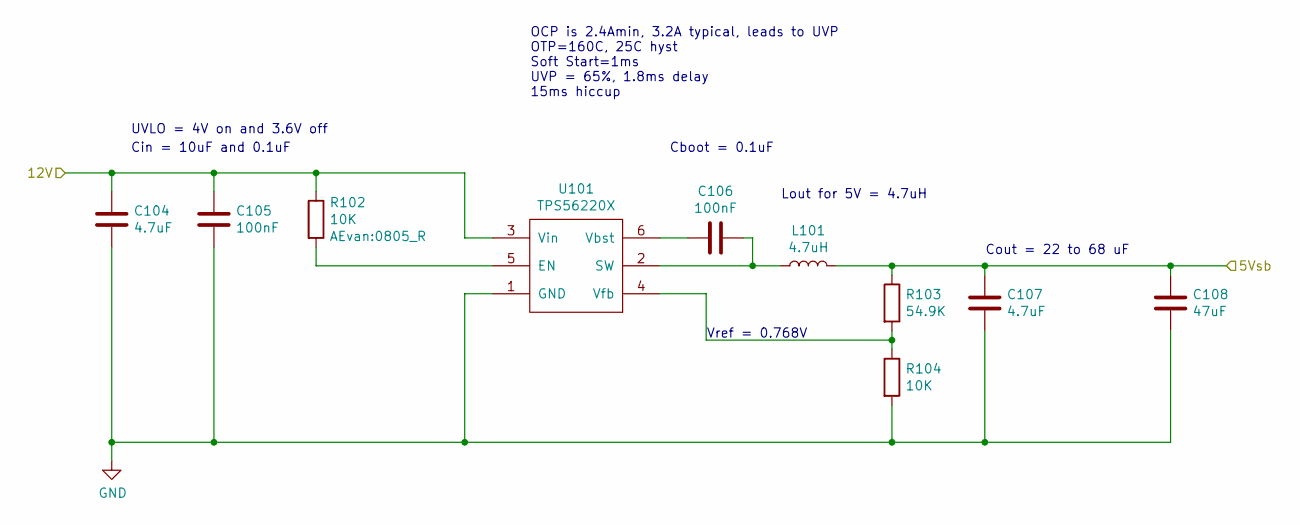
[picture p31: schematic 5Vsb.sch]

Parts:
C104, C107: 4.7uF; 0805_C
C105, C106: 100nF; 0805_C
C108: 47uF; CP_EIA-3528-15_AVX-H; Digikey_PN 718-2167-1-ND
L101: 4.7uH; L_6.3x6.3_H3
R102, R104: 10K; 0805_R
R103: 54.9K; 0805_R
U101: TPS56220X; SOT-23-6_Handsoldering

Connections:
5Vsb: C107.1, C108.1, L101.2, R103.1; also elsewhere on the board
GND: C104.2, C105.2, C107.2, C108.2, R104.2, U101.1 (GND); also elsewhere on the board
unnamed: C106.1, L101.1, U101.2 (SW)
unnamed: C106.2, U101.6 (Vbst)
unnamed: R102.2, U101.5 (EN)
unnamed: R103.2, R104.1, U101.4 (Vfb)
Vstby: C104.1, C105.1, R102.1, U101.3 (Vin); also elsewhere on the board

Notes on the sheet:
Cin = 10uF and 0.1uF
UVLO = 4V on and 3.6V off
Vref = 0.768V
Cboot = 0.1uF
Lout for 5V = 4.7uH
Cout = 22 to 68 uF
OCP is 2.4Amin, 3.2A typical, leads to UVP OTP=160C, 25C hyst Soft Start=1ms UVP = 65%, 1.8ms delay 15ms hiccup

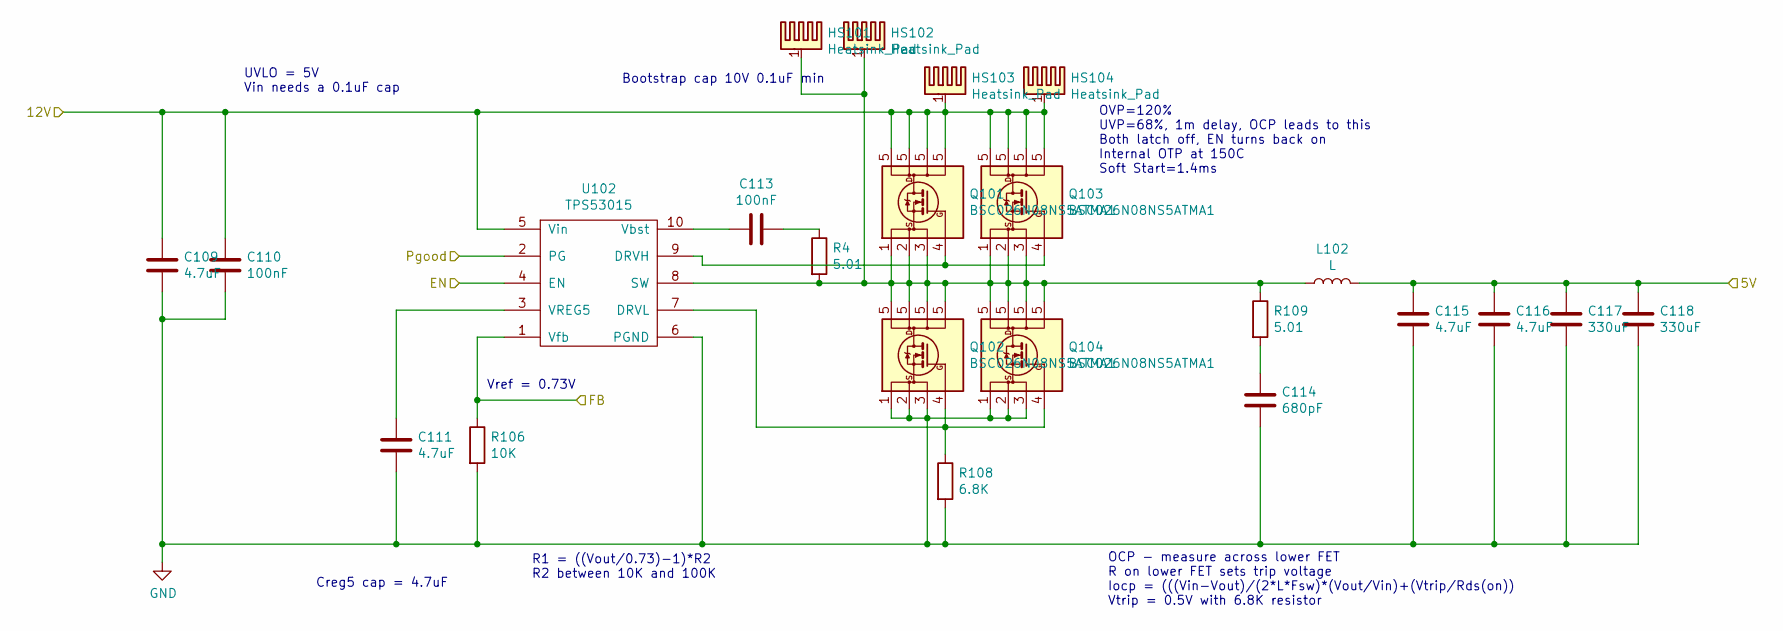
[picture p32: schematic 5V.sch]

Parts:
C109, C111, C115, C116: 4.7uF; 0805_C
C110, C113: 100nF; 0805_C
C114: 680pF; 0805_C
C117, C118: 330uF; C_Radial_D6.3mm_H7.0mm_P2.50mm
HS101, HS102, HS103, HS104: Heatsink_Pad; 5X6-HEATSINK
L102: L; L_12x12mm_H8mm
Q101, Q102, Q103, Q104: BSC026N08NS5ATMA1; TDSON-8-1
R4, R109: 5.01; 0805_R
R106: 10K; 0805_R
R108: 6.8K; 0805_R
U102: TPS53015; VSSOP-10_2.4x2.1mm_Pitch0.5mm

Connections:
3V3: C115.1, C116.1, C117.1, C118.1, L102.2; also elsewhere on the board
/5V/EN: U102.4 (EN); also elsewhere on the board
/5V/FB: R106.1, U102.1 (Vfb); also elsewhere on the board
/24pinATX/PWOK: U102.2 (PG); also elsewhere on the board
GND: C109.2, C110.2, C111.2, C114.2, C115.2, C116.2, C117.2, C118.2, Q102.1 (S), Q102.2 (S), Q102.3 (S), Q104.1 (S), Q104.2 (S), Q104.3 (S), R106.2, R108.2, U102.6 (PGND); also elsewhere on the board
unnamed: C111.1, U102.3 (VREG5)
unnamed: C113.1, R4.1
unnamed: C113.2, U102.10 (Vbst)
unnamed: C114.1, R109.2
unnamed: HS101.1, HS102.1, L102.1, Q101.1 (S), Q101.2 (S), Q101.3 (S), Q102.5 (D), Q103.1 (S), Q103.2 (S), Q103.3 (S), Q104.5 (D), R4.2, R109.1, U102.8 (SW)
unnamed: Q101.4 (G), Q103.4 (G), U102.9 (DRVH)
unnamed: Q102.4 (G), Q104.4 (G), R108.1, U102.7 (DRVL)
Vmain: C109.1, C110.1, HS103.1, HS104.1, Q101.5 (D), Q103.5 (D), U102.5 (Vin); also elsewhere on the board

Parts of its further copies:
C2, C4, C7, C8: 4.7uF; 0805_C
C3, C5: 100nF; 0805_C
C6: 680pF; 0805_C
C9, C10: 330uF; C_Radial_D6.3mm_H7.0mm_P2.50mm
HS1, HS2, HS3, HS4: Heatsink_Pad; 5X6-HEATSINK
L1: L; L_12x12mm_H8mm
Q1, Q2, Q3, Q4: BSC026N08NS5ATMA1; TDSON-8-1
R10: 10K; 0805_R
R11, R13: 5.01; 0805_R
R12: 6.8K; 0805_R
U1: TPS53015; VSSOP-10_2.4x2.1mm_Pitch0.5mm

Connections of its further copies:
5V: C7.1, C8.1, C9.1, C10.1, L1.2; also elsewhere on the board
/5V/EN: U1.2 (PG); also elsewhere on the board
/sheet603813B5/FB: R10.1, U1.1 (Vfb); also elsewhere on the board
GND: C2.2, C3.2, C4.2, C6.2, C7.2, C8.2, C9.2, C10.2, Q2.1 (S), Q2.2 (S), Q2.3 (S), Q4.1 (S), Q4.2 (S), Q4.3 (S), R10.2, R12.2, U1.6 (PGND); also elsewhere on the board
unnamed: C4.1, U1.3 (VREG5)
unnamed: C5.1, R11.1
unnamed: C5.2, U1.10 (Vbst)
unnamed: C6.1, R13.2
unnamed: HS1.1, HS2.1, L1.1, Q1.1 (S), Q1.2 (S), Q1.3 (S), Q2.5 (D), Q3.1 (S), Q3.2 (S), Q3.3 (S), Q4.5 (D), R11.2, R13.1, U1.8 (SW)
unnamed: Q1.4 (G), Q3.4 (G), U1.9 (DRVH)
unnamed: Q2.4 (G), Q4.4 (G), R12.1, U1.7 (DRVL)
PWOK: U1.4 (EN); also elsewhere on the board
Vmain: C2.1, C3.1, HS3.1, HS4.1, Q1.5 (D), Q3.5 (D), U1.5 (Vin); also elsewhere on the board

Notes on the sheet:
OVP=120% UVP=68%, 1m delay, OCP leads to this Both latch off, EN turns back on Internal OTP at 150C Soft Start=1.4ms
Bootstrap cap 10V 0.1uF min
UVLO = 5V Vin needs a 0.1uF cap
Creg5 cap = 4.7uF
R1 = ((Vout/0.73)-1)*R2 R2 between 10K and 100K
Vref = 0.73V
OCP - measure across lower FET R on lower FET sets trip voltage Iocp = (((Vin-Vout)/(2*L*Fsw)*(Vout/Vin)+(Vtrip/Rds(on)) Vtrip = 0.5V with 6.8K resistor

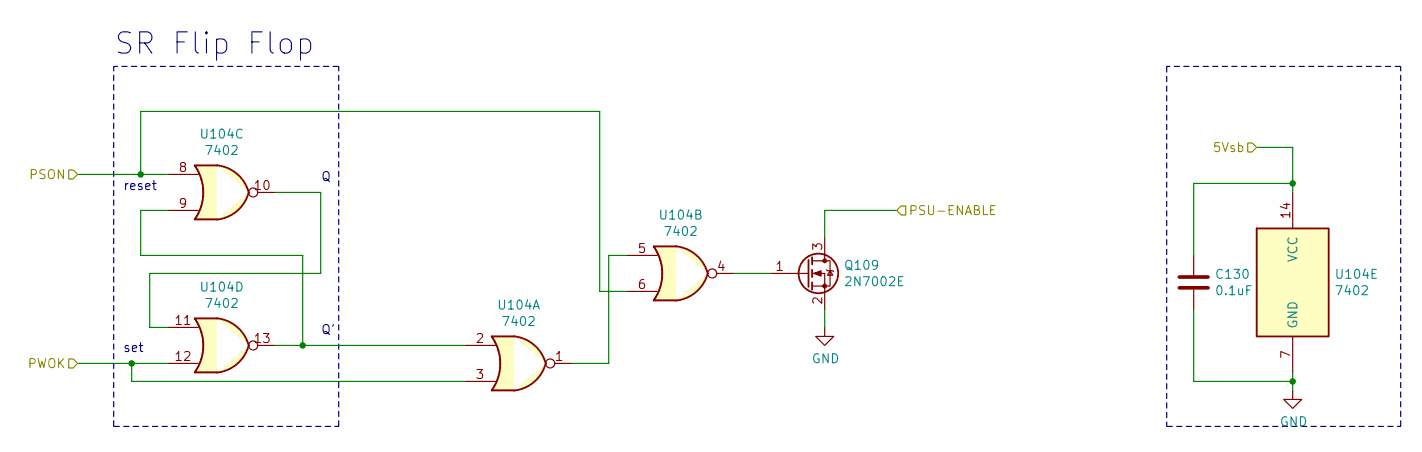
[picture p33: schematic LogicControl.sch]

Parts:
C130: 0.1uF; 0805_C
Q109: 2N7002E; SOT-23
U104: 7402; SOIC-14W_7.5x9mm_P1.27mm

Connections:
5Vsb: C130.1, U104.14 (VCC); also elsewhere on the board
/24pinATX/PSON: U104.6, U104.8; also elsewhere on the board
/24pinATX/PWOK: U104.3, U104.12; also elsewhere on the board
GND: C130.2, Q109.2 (S), U104.7 (GND); also elsewhere on the board
unnamed: Q109.1 (G), U104.4
unnamed: U104.1, U104.5
unnamed: U104.10, U104.11
unnamed: U104.2, U104.9, U104.13
PSON: Q109.3 (D); also elsewhere on the board

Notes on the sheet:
SR Flip Flop
set
reset

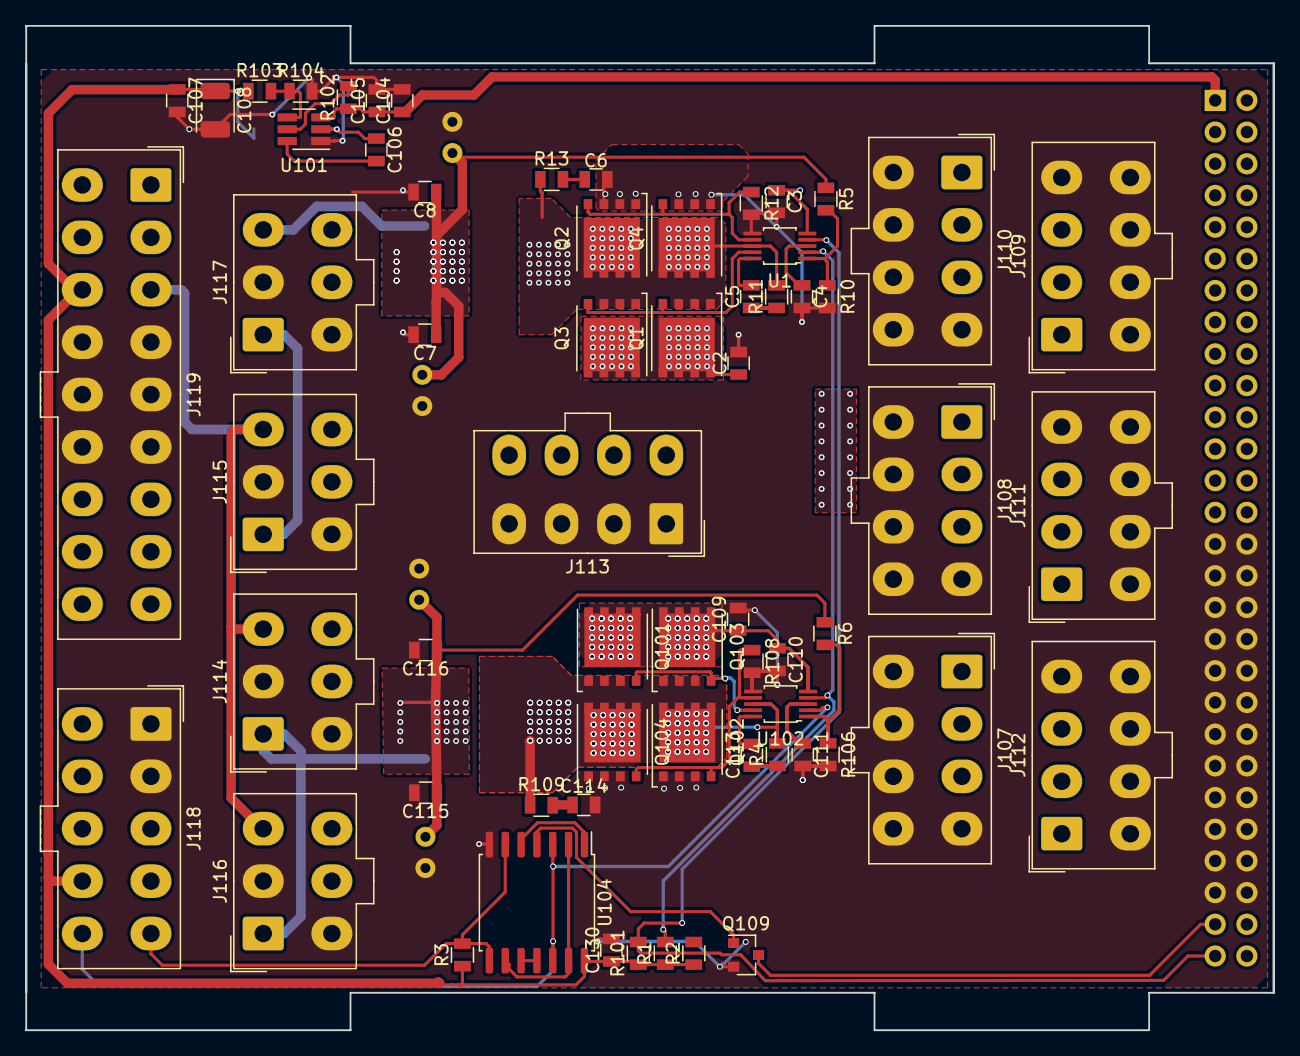
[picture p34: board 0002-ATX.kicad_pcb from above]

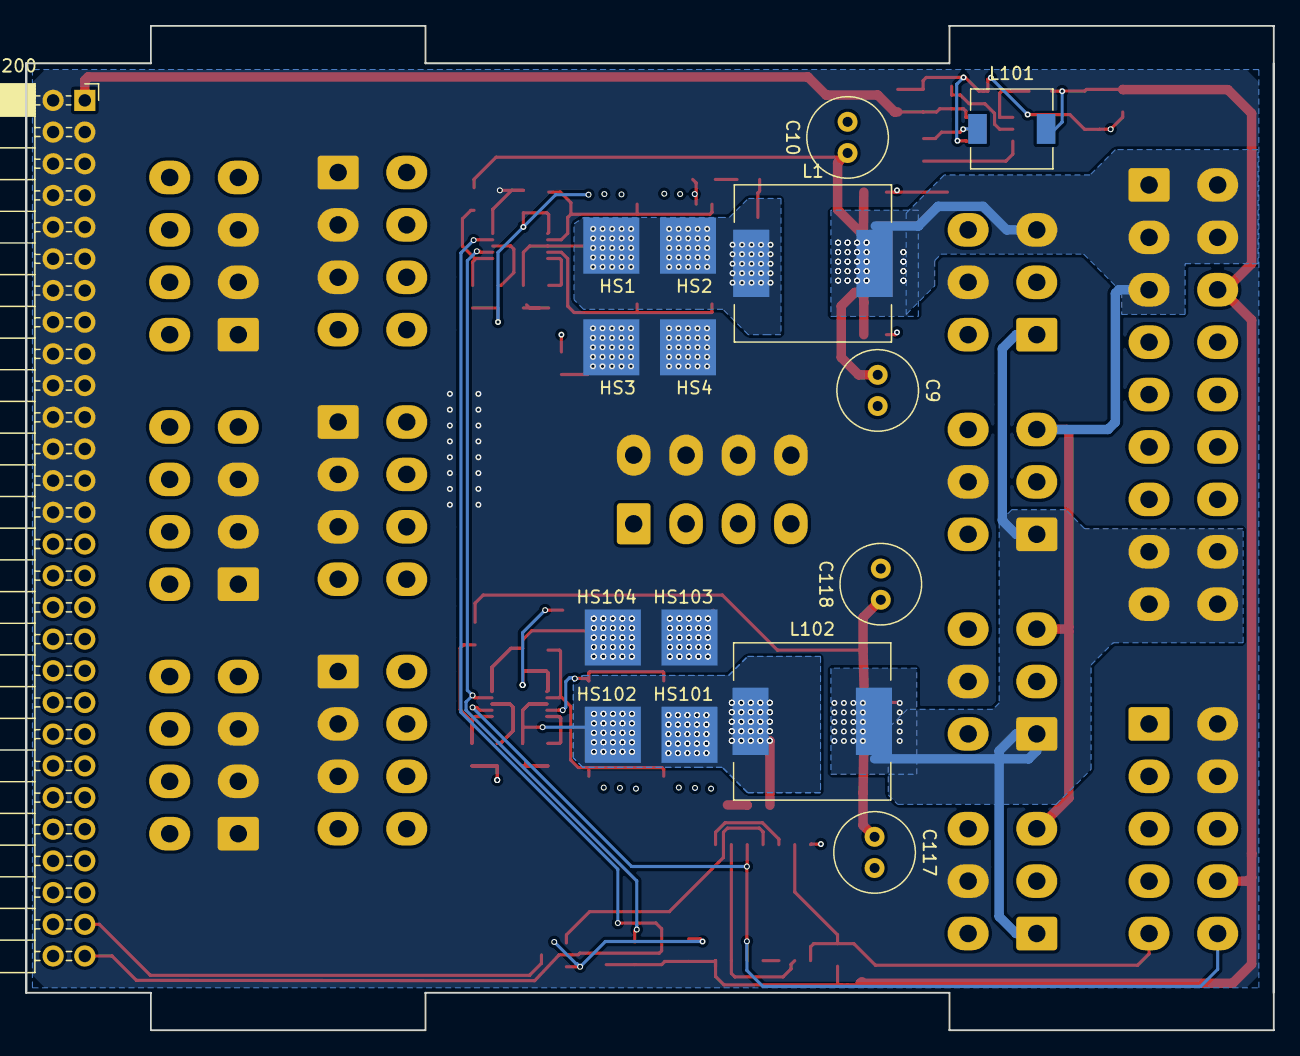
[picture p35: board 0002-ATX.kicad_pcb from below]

Board: 2 copper layers, 100.0 x 80.5 mm, 79 parts (16 on the bottom side), 35 nets.

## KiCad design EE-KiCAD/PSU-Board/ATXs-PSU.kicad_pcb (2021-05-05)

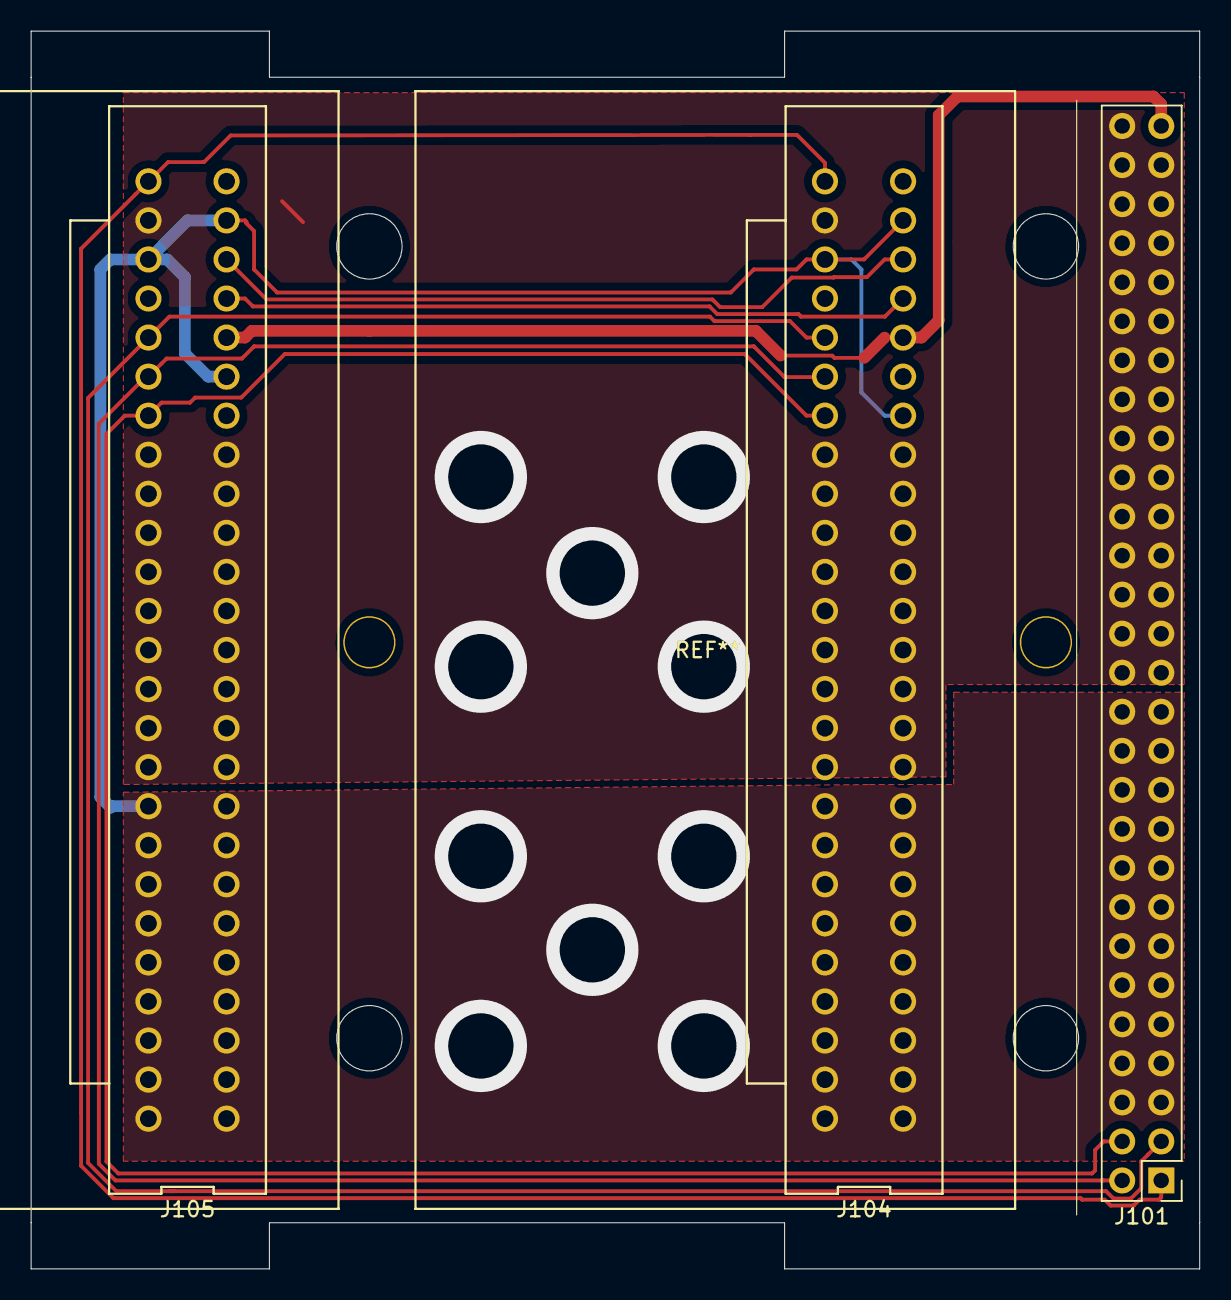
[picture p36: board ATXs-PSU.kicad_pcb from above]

Board: 2 copper layers, 76.0 x 80.5 mm, 3 parts (0 on the bottom side), 9 nets.

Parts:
J101: Conn_02x28_Odd_Even; PinHeader_2x28_P2.54mm_Vertical
J104, J105: Conn_02x25_Row_Letter_First; CRPS_FCI_10035388-102LF

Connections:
/CRPS_PSU/CR_BUS: J104.b22, J105.b22
/CRPS_PSU/CurrentShare: J104.b23, J105.b23
GND: J101.5, J101.6, J101.7, J101.8, J101.9, J101.10, J101.11, J101.12, J101.13, J101.14, J101.15, J101.16, J101.17, J101.18, J101.19, J101.20, J101.21, J101.22, J101.23, J101.24, J101.25, J101.26, J104.a1, J104.a2, J104.a3, J104.a4, J104.a5, J104.a6, J104.a7, J104.a8, J104.a9, J104.a23, J104.b1, J104.b2, J104.b3, J104.b4, J104.b5, J104.b6, J104.b7, J104.b8, J104.b9, J104.b19, J104.b24, J105.a1, J105.a2, J105.a3, J105.a4, J105.a5, J105.a6, J105.a7, J105.a8, J105.a9, J105.a23, J105.b1, J105.b2, J105.b3, J105.b4, J105.b5, J105.b6, J105.b7, J105.b8, J105.b9, J105.b20, J105.b24
PSON: J101.3, J104.a21, J105.a21
PWOK: J101.1, J104.a25, J105.a25
SCL: J101.2, J104.a20, J105.a20
SDA: J101.4, J104.a19, J105.a19
Vmain: J101.27, J101.28, J101.29, J101.30, J101.31, J101.32, J101.33, J101.34, J101.35, J101.36, J101.37, J101.38, J101.39, J101.40, J101.41, J101.42, J101.43, J101.44, J101.45, J101.46, J101.47, J101.48, J101.49, J101.50, J101.51, J101.52, J101.53, J101.54, J101.56, J104.a10, J104.a11, J104.a12, J104.a13, J104.a14, J104.a15, J104.a16, J104.a17, J104.a18, J104.a24, J104.b10, J104.b11, J104.b12, J104.b13, J104.b14, J104.b15, J104.b16, J104.b17, J104.b18, J105.a10, J105.a11, J105.a12, J105.a13, J105.a14, J105.a15, J105.a16, J105.a17, J105.a18, J105.a24, J105.b10, J105.b11, J105.b12, J105.b13, J105.b14, J105.b15, J105.b16, J105.b17, J105.b18
Vstby: J101.55, J104.b21, J105.b21

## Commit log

2021-01-27 Add initial Mechanical Design
    [ATXs.scad]
2021-01-28 Updates to mechanical Model. Add picture for github.
    [ATXs.scad]
2021-02-23 First draft of circuit boards, Updated Enclosure
    [0002-ATX-2018-08-03-05-46-12.sch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]
2021-02-26 Finish first draft of PCBs. Pulled PCBs into OpenSCAD for fitment.
    [0002-ATX.kicad_pcb, 0002-ATX.sch, 24pinATX.sch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]
2021-03-05 Fitted PSUs into enclosure. Aligned PSU PCB.
    [ATXs-PSU.kicad_pcb, ATXs-PSU.sch, ATXs.3mf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]
2021-05-05 add tabs on PCBs to set where they are in the box. Box adjustments.
    [0002-ATX.kicad_pcb, 0002-ATX.sch, 039288060.stp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]
